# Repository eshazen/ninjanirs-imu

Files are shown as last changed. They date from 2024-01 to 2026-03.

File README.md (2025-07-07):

# ninjanirs-imu

IMU and multiplexer designs for ninjaNIRS.  PCBs in this repo:

* `KiCAD/imu-adapter` - programming adapter for MCU programming (for V1 and V2)
* `KiCAD/imu-board` - the IMU board.  Now V2.  Accommodates an optional RJ-11 jack on the back
* `KiCAD/imu-rj-adapter` - RJ-11 adapter for V1 IMU boards (obsolete)
* `KiCAD/imu-splitter` - splitter for connecting IMU to NinjaNIRS readout via ribbon cable (for V1 and V2)

## IMU Board

Board designed in early 2024 along with various adapters and a splitter.
The IMU board has an ATMeg168 so plenty of resources.

### UART connector pinout

    1 - VCC (5V or 3.3V)
	2 - TxD (output from MCU)
	3 - RxD (input to MCU)
	4 - GND
	
### RJ Adapter board pinout

    GND     1
	RxD        2
	TxD     3
	VCC        4

### Using IMU with other systems

The IMU can be used with systems other than NinjaNIRS (fNIRS).  See [OTHERS.md](OTHERS.md) for details.

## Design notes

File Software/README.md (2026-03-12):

# NN24 IMU board software

## Notes

MCU is an ATmega168 in a 28MLF package.

Pinout:

	22 PC3 - LED
    23 PC4 - SDA  (hardware TWI)
	24 PC5 - SCL  (hardware TWI)
	26 PD0 - RxD  (USART Rx)
	27 PD1 - TxD  (USART Tx)
	
Software should be pretty straightforward, since the built-in peripherals can be used.

## Software in this folder

| Folder | Description |
|---|---|
| `arduino-demo` | C code (not Arduino) to test the IMU on an Arduino uno |
| | Prints lines of text with 7 values |
| | |
| `avr-imu-readout` | (obsolete readout software) |
| | Either wait for command byte or timer |
| | Send data in binary or CSV |
| | |
| `avr-imu-blinky` | Blink the LED for quick hardware test |
| | |
| `avr-imu-led-test`  | Read the IMU and encode somehow on the LED |
| | (for easy testing without a UART) |
| | |
| `avr-imu-gpio-test` | **AVR software to readout IMU** |
| | Version using UART Rx as edge trigger for readout |
| | As used by fNIRS at 250k baud (set in `uart.h`) |
| | As used by senior design team 2025 at 9600 baud |
| | |
| `linux-imu-client`  | Linux client to read and display binary data from IMU  |
| | |
| `python-imu` | Python client `imu_250k_test.py` reads fNIRS version |
| | at 250k baud and displays |
| | |
| `BZ_example_code` | Yes |
| | |

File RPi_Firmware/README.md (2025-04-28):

# Raspberry Pi RP2040 Firmware

This directory has firmware images from Bernhard.

`IMUAdapterTestFirmware.uf2` -- Initial version tested 4/2025.  May have J2 Tx/Rx swap.

`IMUAdapterTestFirmware_20250418.uf2` -- Updated version of 4/22/25.  <br>Changes:

* Well defined sample rate of 20 Hz
* Sampling of a 'Sync IN' digital input, and output of its value at the end of the IMU data line
* Corrected the RX/TX swap on J2 of the splitter

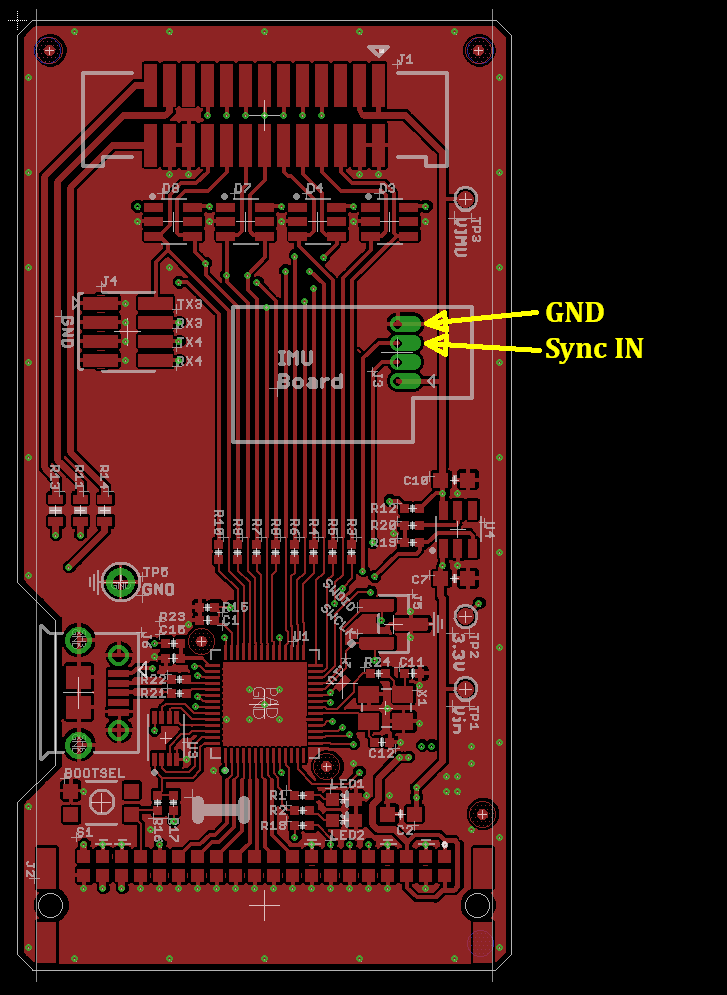
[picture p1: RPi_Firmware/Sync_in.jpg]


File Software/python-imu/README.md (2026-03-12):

# Python test script

`imu_250k_test.py` works for "standard" fNIRS firmware.  This firmware triggers
a readout on any Rx data on the UART and sends a binary frame as below.
The bit rate is 250k.  This works on Linux with an FTDI interface, YMMV.

    Expected binary output:
      <echo> <count> <length> <checksum>
    
    offset 0      <echo>     = xx   echo of byte received
    offset 1      <count>    = 14   normal data, 
    offset 2..15  <data>     =      (7) 16-bit words of Temp, GyroX/Y/Z, Accel X/Y/Z
    offset 16     <checksum> =      uint8_t sum of bytes at offset 1..15
    
    if any error occurs, <count> = 1 and the error code is somehow related
    to the I2C error.

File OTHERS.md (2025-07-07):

# Using the IMU with other systems

This page has some information for using the IMU with non- NinjaNIRS (fNIRS) systems.

The small IMU board comes in two versions.

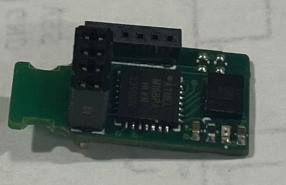
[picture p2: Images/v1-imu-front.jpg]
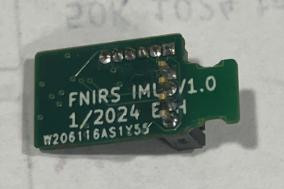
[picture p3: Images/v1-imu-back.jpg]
V1:    

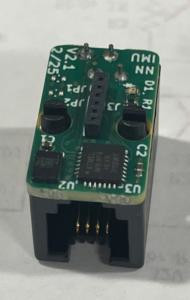
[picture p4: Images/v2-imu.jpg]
V2:  

Both can be used.  The V1 board requires either wires soldered
directly to the board or a separate adapter board which connects to an RJ-11 (modular) jack.

Adapter:  

## Connector Pinouts

| Pin No | Function | Notes |
|---|---|---|
| 1 | VCC | 3.3V power |
| 2 | TxD | Data out from IMU |
| 3 | RxD | Data in or trigger to IMU |
| 4 | GND | Ground |

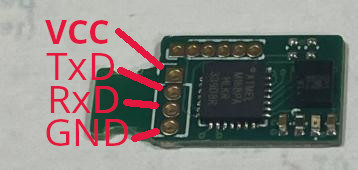
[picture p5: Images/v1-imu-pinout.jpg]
V1 Pinout: 

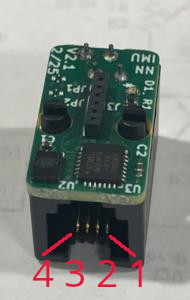
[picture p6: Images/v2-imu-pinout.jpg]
V2 Pinout: 

Pin 2 provides the data out from the IMU.  The firmware supplied for
"other" (non-fNIRS) users can be compiled with various options, but
the usual one is that a pulse on the `RxD` pin causes the IMU data to
be read and transmitted on the `TxD` pin.

Data is transmitted using the asynchronous serial protocol (aka "UART") at 9600 baud.

The default data format is three 16-bit integers separated by commas,
representing acceleration along the X, Y and Z axis.

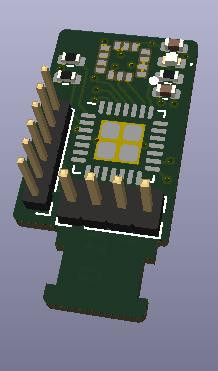
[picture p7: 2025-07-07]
Images/v1-imu-3d.jpg

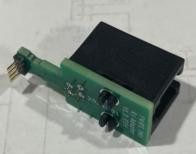
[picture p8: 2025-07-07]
Images/adapter.jpg

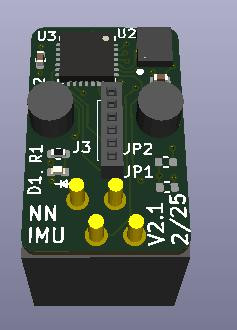
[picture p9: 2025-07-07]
Images/v2-imu-3d.jpg

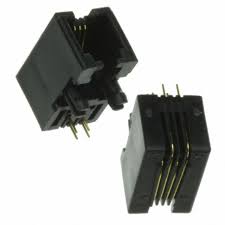
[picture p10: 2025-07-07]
Images/rj11.jpeg

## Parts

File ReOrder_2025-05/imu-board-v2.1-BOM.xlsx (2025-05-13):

 |  |  | NinjaNIRS IMU V2.0 Bill of Materials For Boston University
Item # | *Designator | *Qty | Manufacturer | *Mfg Part # | Description / Value | *Package/Footprint | Type | Your Instructions / Notes
1 | C1, C2 | 1 | KYOCERA | 0402YC104KAT4A | CAP CER 0.1UF 16V X7R 0402 | 0402 (1005 Metric) | SMD
2 | D1 | 1 | SUNLED | XZMDK68W-2 | LED RED CLEAR CHIP SMD | 0402 (1005 Metric) | SMD
3 | R1 | 1 | WALSIN | WR04X6800FTL | RES 680 OHM 1% 1/16W 0402 | 0402 (1005 Metric) | SMD
4 | U2 | 1 | ST | ISM330DHCXTR | INEMO INERTIAL MODULE: ALWAYS-ON | 14-LGA | SMD
5 | U3 | 1 | MICROCHIP | ATMEGA168PA-MMHR | IC MCU 8BIT 16KB FLASH 28VQFN | 28-VQFN | SMD
6 | J3 | 1 | GCT | BC065-06-A-L-D | 6POS 1.0MM PITCH SOCKET, SIL, TH | 6-SIL 1MM | THD
Need a quick and accurante quote? Need an efficient production? Please read SMT Ordering Necessary Files & Info in 1 minute. Thank you very much! (https://www.pcbway.com/smt_ordering_guide.html)
Click for Instructions on How to Create a BOM (https://www.pcbway.com/blog/PCB_Assembly/How_to_Build_a_BOM__Bill_Of_Materials_.html)

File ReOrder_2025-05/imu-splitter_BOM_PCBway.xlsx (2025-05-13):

 |  |  | NinjaNIRS IMU Splitter V2.0 Bill of Materials For Boston University
Item # | *Designator | *Qty | Manufacturer | *Mfg Part # | Description / Value | *Package/Footprint | Type | Your Instructions / Notes
1 | C1 | 1 | Samsung | CL21A106KOQNNNE | 10uF | 0805 | SMD
2 | C2 | 1 | Samsung | CL21A226KOQNNNE | 22uF | 0805 | SMD
3 | D1,D2 | 2 | Dialight | 5973006607F | LED | 0805 | SMD
4 | J1,J2,J3,J4,J5,J6 | 6 | Assman | A-2004-3-4-LP-N-R | CONN MOD JACK 4P4C R/A UNSHLD | MOD JACK | THD
5 | J7 | 1 | CNC Tech | 3220-26-0200-00 | CONN HEADER R/A 26POS 1.27MM | 26 POS 1.27MM | THD
6 | J8 | 1 | Samtec | TMS-104-01-G-S | CONN HEADER VERT 4POS 1.27MM | 4 POS 1.27MM | THD
7 | J9 | 1 | Amphenol | 68000-105HLF | CONN HEADER VERT 5POS 2.54MM | 5 POS 2.54MM | THD
8 | R1 | 1 | Yageo | RC0805FR-071K5L | RES 1.5K OHM 1% 1/8W 0805 | 0805 | SMD
9 | R2 | 1 | Yageo | RC0805FR-07510RL | RES 510 OHM 1% 1/8W 0805 | 0805 | SMD
10 | U1 | 1 | Diodes Inc | AZ1117CH-3.3TRG1 | IC REG LINEAR 3.3V 1A SOT223 | SOT223 | SMD
Need a quick and accurante quote? Need an efficient production? Please read SMT Ordering Necessary Files & Info in 1 minute. Thank you very much! (https://www.pcbway.com/smt_ordering_guide.html)
Click for Instructions on How to Create a BOM (https://www.pcbway.com/blog/PCB_Assembly/How_to_Build_a_BOM__Bill_Of_Materials_.html)

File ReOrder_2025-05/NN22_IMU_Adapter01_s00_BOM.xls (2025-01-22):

PCBWay Bom Quotation, Product No.:T-1Y54W206116A
Item # | *Designator | *Qty | *Mfg Part # | Description / Value | *Package/Footprint | Mounting Type | *Unit Price(4 sets) | *Total | *Delivery Time | *Actual Purchase Mfg Part # | *PCBWay Note | Customer Reply
1 | LED1 | 1 | LTST-C191KRKT | LED RED CLEAR SMD | LED-0603 | SMD | $0.029 | $0.116
2 | LED2 | 1 | LTST-C191KGKT | LED GREEN CLEAR SMD | LED-0603 | SMD | $0.031 | $0.124
3 | C1, C3, C6, C8, C9, C16, C17, C18, C19, C20, C21, C22, C23, C24 | 14 | GRM155R71H104KE14D | CAP CER 0.1UF 50V X7R 0402『 』0.1u『 』0.1u | 0402-CAP | SMD | $0.014 | $0.784
4 | R1, R2, R10, R16, R24 | 5 | RC0402FR-071K2L | RES 1.2K OHM 1% 1/16W 0402『 』1.2k『 』1.2k | 0402-RES | SMD | $0.004 | $0.080
5 | R3, R4, R5, R6, R7, R8, R9 | 7 | RC0402FR-0710RL | 10 Ohms ±1% 0.063W, 1/16W Chip Resistor 0402 (1005 Metric) Moisture Resistant Thick Film『 』10 | 0402-RES | SMD | $0.004 | $0.112
6 | R12, R15, R17, R18, R19, R25, R26 | 7 | RC0402FR-07100KL | RES 100K OHM 1% 1/16W 0402『 』100k『 』100k | 0402-RES | SMD | $0.003 | $0.084
7 | C2, C7, C10 | 3 | GRM188R6YA106MA73D | CAP CER 10UF 35V X5R 0603『 』10u『 』10u | 0603-CAP | SMD | $0.149 | $1.788
8 | R21, R22, R27, R28 | 4 | RC0402FR-0727RL | RES 27 OHM 1% 1/16W 0402『 』27『 』27 | 0402-RES | SMD | $0.005 | $0.080
9 | C11, C12 | 2 | GCM1555C1H270JA16D | CAP CER 27PF 50V C0G/NP0 0402『 』27p『 』27p | 0402-CAP | SMD | $0.088 | $0.704
10 | R23 | 1 | CRCW040233R0FKEDC | RES 33 OHM 1% 1/16W 0402『 』33『 』33 | 0402-RES | SMD | $0.161 | $0.644
11 | C4, C5, C13, C14, C15 | 5 | CL05A475MP5NRNC | CAP CER 4.7UF 10V X5R 0402『 』4.7u『 』4.7u | 0402-CAP | SMD | $0.027 | $0.540
12 | R20 | 1 | RC0402FR-0782KL | RES 82K OHM 1% 1/16W 0402『 』82k | 0402-RES | SMD | $0.012 | $0.048
13 | U4 | 1 | AP22653AW6-7 | LOAD SWITCH,SOT26,T&R,3K『 』AP2265X_SOT | SOT23-6 | SMD | $0.308 | $1.232
14 | D9, D10 | 2 | BAV70WT1G | DIODE ARRAY GP 100V 200MA SC70-3『 』BAV70W | SOT323 | SMD | $0.095 | $0.760
15 | X1 | 1 | 403I35D12M00000 | CRYSTAL 12.0000MHZ 18PF SMD『 』CRYSTAL-3.2-2.5『 』CRYSTAL-3.2-2.5 | CRYSTAL-3.2-2.5 | SMD | $0.798 | $3.192 | 7-10 Workdays
16 | D1, D2, D3, D4, D5, D6, D7, D8 | 8 | D1213A-02SO-7 | TVS DIODE 3.3VWM 10VC SOT26『 』D1213A-02SO | SOT23-6 | SMD | $0.153 | $4.896
17 | R11, R13, R14 | 3 |  | DNP | 0603-RES | DNP |  |  |  |  | [DNP不要贴];
18 | FID1, FID2, FID3, FID4, FID5, FID6, FID7, FID8 | 8 |  | FIDUCIALUFIDUCIAL | MICRO-FIDUCIAL | DNP |  |  |  |  | [DNP不要贴];
20 | J5 | 1 | SM03B-SRSS-TB | CONN HEADER SMD R/A 3POS 1MM |  | SMD
21 | J3, J4 | 2 |  | M04X2_0.050_SMD_NO_CREAM | M04X2_0.050_SMD_NO_CREAM | DNP |  |  |  |  | [DNP不要贴];
22 | J1 | 1 | 3220-26-0300-00 | CONN HEADER SMD 26POS 1.27MM『 』M13X2_0.050_SHF | M13X2_0.050_SHF | SMD | $2.138 | $8.552 | 7-10 Workdays
23 | J2 | 1 | 15150402601000 | CONN HEADER SMD R/A 40POS 1.27MM『 』M20X2_HARFLEX_M | M20X2_HARFLEX_M | SMD | $6.766 | $27.064 | 7-10 Workdays
24 | U2 | 1 | MCP1755-3302E/MC | IC REG LINEAR 3.3V 300MA 8DFN『 』MCP1755_DFN『 』MCP1755_DFN | DFN8_2X3MM | SMD | $1.096 | $4.384 | 7-10 Workdays
25 | U1 | 1 | SC0914(7) | IC MCU 32BIT EXT MEM 56QFN『 』RP2040『 』RP2040 | QFN-56_EP | SMD | $1.441 | $5.764 | 7-10 Workdays
26 | S1 | 1 | KMR231NG LFS | SWITCH TACTILE SPST-NO 0.05A 32V『 』SWITCH-MOMENTARY-2SMD-3『 』SWITCH-MOMENTARY-2SMD-3 | TACTILE_SWITCH_SMD-3 | SMD | $0.910 | $3.640 |  | KMR231NGLFS
27 | TP5 | 1 |  | TESTPOINT1X01 | 1X01 | DNP |  |  |  |  | [DNP不要贴];
28 | TP4 | 1 |  | TESTPOINTPADSMALL | TESTPAD_SMALL | DNP |  |  |  |  | [DNP不要贴];
29 | TP1, TP2, TP3 | 3 |  | TESTPOINT_ROUND | TESTPAD_ROUND | DNP |  |  |  |  | [DNP不要贴];
30 | J6 | 1 | 10118194-0001LF | CONN RCPT USB2.0 MICRO B SMD R/A『 』USB-MICRO『 』USB-MICRO | USB-MICRO | SMD/PTH | $0.318 | $1.272
31 | U3 | 1 | W25Q16JVUXIQ TR | IC FLASH 16MBIT SPI/QUAD 8USON『 』W25Q_USON『 』W25Q_USON | USON8L-2X3MM | SMD | $0.889 | $3.556 | 7-10 Workdays
32 | U5 | 1 | ISM330DHCXTR | Accelerometer, Gyroscope, Temperature, 6 Axis Sensor I2C, SPI Output | LGA14-L | SMD
 |  |  |  |  |  |  | Component Cost | $69.42

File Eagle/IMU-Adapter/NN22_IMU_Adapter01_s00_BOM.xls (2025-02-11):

PCBWay BOM for IMU adapter
Item # | *Designator | *Qty | *Mfg Part # | Description / Value | *Package/Footprint | Mounting Type | *Unit Price(4 sets) | *Total | *Delivery Time | *Actual Purchase Mfg Part # | *PCBWay Note | Customer Reply
1 | LED1 | 1 | LTST-C191KRKT | LED RED CLEAR SMD | LED-0603 | SMD
2 | LED2 | 1 | LTST-C191KGKT | LED GREEN CLEAR SMD | LED-0603 | SMD
3 | C1, C3, C6, C8, C9, C16, C17, C18, C19, C20, C21, C22, C23, C24 | 14 | GRM155R71H104KE14D | CAP CER 0.1UF 50V X7R 0402『 』0.1u『 』0.1u | 0402-CAP | SMD
4 | R1, R2, R10, R16, R24 | 5 | RC0402FR-071K2L | RES 1.2K OHM 1% 1/16W 0402『 』1.2k『 』1.2k | 0402-RES | SMD
5 | R3, R4, R5, R6, R7, R8, R9 | 7 | RC0402FR-0710RL | 10 Ohms ±1% 0.063W, 1/16W Chip Resistor 0402 (1005 Metric) Moisture Resistant Thick Film『 』10 | 0402-RES | SMD
6 | R12, R15, R17, R18, R19, R25, R26 | 7 | RC0402FR-07100KL | RES 100K OHM 1% 1/16W 0402『 』100k『 』100k | 0402-RES | SMD
7 | C2, C7, C10 | 3 | GRM188R6YA106MA73D | CAP CER 10UF 35V X5R 0603『 』10u『 』10u | 0603-CAP | SMD
8 | R21, R22, R27, R28 | 4 | RC0402FR-0727RL | RES 27 OHM 1% 1/16W 0402『 』27『 』27 | 0402-RES | SMD
9 | C11, C12 | 2 | GCM1555C1H270JA16D | CAP CER 27PF 50V C0G/NP0 0402『 』27p『 』27p | 0402-CAP | SMD
10 | R23 | 1 | CRCW040233R0FKEDC | RES 33 OHM 1% 1/16W 0402『 』33『 』33 | 0402-RES | SMD
11 | C4, C5, C13, C14, C15 | 5 | CL05A475MP5NRNC | CAP CER 4.7UF 10V X5R 0402『 』4.7u『 』4.7u | 0402-CAP | SMD
12 | R20 | 1 | RC0402FR-0782KL | RES 82K OHM 1% 1/16W 0402『 』82k | 0402-RES | SMD
13 | U4 | 1 | AP22653AW6-7 | LOAD SWITCH,SOT26,T&R,3K『 』AP2265X_SOT | SOT23-6 | SMD
14 | D9, D10 | 2 | BAV70WT1G | DIODE ARRAY GP 100V 200MA SC70-3『 』BAV70W | SOT323 | SMD
15 | X1 | 1 | 403I35D12M00000 | CRYSTAL 12.0000MHZ 18PF SMD『 』CRYSTAL-3.2-2.5『 』CRYSTAL-3.2-2.5 | CRYSTAL-3.2-2.5 | SMD
16 | D1, D2, D3, D4, D5, D6, D7, D8 | 8 | D1213A-02SO-7 | TVS DIODE 3.3VWM 10VC SOT26『 』D1213A-02SO | SOT23-6 | SMD
17 | R11, R13, R14 | 3 |  | DNP | 0603-RES | DNP
18 | FID1, FID2, FID3, FID4, FID5, FID6, FID7, FID8 | 8 |  | FIDUCIALUFIDUCIAL | MICRO-FIDUCIAL | DNP
20 | J5 | 1 | SM03B-SRSS-TB | CONN HEADER SMD R/A 3POS 1MM |  | SMD
21 | J3, J4 | 2 |  | M04X2_0.050_SMD_NO_CREAM | M04X2_0.050_SMD_NO_CREAM | DNP
22 | J1 | 1 | 3220-26-0300-00 | CONN HEADER SMD 26POS 1.27MM『 』M13X2_0.050_SHF | M13X2_0.050_SHF | SMD
23 | J2 | 1 | 15150402601000 | CONN HEADER SMD R/A 40POS 1.27MM『 』M20X2_HARFLEX_M | M20X2_HARFLEX_M | SMD
24 | U2 | 1 | MCP1755-3302E/MC | IC REG LINEAR 3.3V 300MA 8DFN『 』MCP1755_DFN『 』MCP1755_DFN | DFN8_2X3MM | SMD
25 | U1 | 1 | SC0914(7) | IC MCU 32BIT EXT MEM 56QFN『 』RP2040『 』RP2040 | QFN-56_EP | SMD
26 | S1 | 1 | KMR231NG LFS | SWITCH TACTILE SPST-NO 0.05A 32V『 』SWITCH-MOMENTARY-2SMD-3『 』SWITCH-MOMENTARY-2SMD-3 | TACTILE_SWITCH_SMD-3 | SMD
27 | TP5 | 1 |  | TESTPOINT1X01 | 1X01 | DNP
28 | TP4 | 1 |  | TESTPOINTPADSMALL | TESTPAD_SMALL | DNP
29 | TP1, TP2, TP3 | 3 |  | TESTPOINT_ROUND | TESTPAD_ROUND | DNP
30 | J6 | 1 | 10118194-0001LF | CONN RCPT USB2.0 MICRO B SMD R/A『 』USB-MICRO『 』USB-MICRO | USB-MICRO | SMD/PTH
31 | U3 | 1 | W25Q16JVUXIQ TR | IC FLASH 16MBIT SPI/QUAD 8USON『 』W25Q_USON『 』W25Q_USON | USON8L-2X3MM | SMD
32 | U5 | 1 | ISM330DHCXTR | Accelerometer, Gyroscope, Temperature, 6 Axis Sensor I2C, SPI Output | LGA14-L | SMD

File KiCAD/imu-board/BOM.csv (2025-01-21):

Reference | Value | Footprint | Qty | DNP | CatNo | MfgNo
C1,C2 | 0.1uF | Capacitor_SMD:C_0402_1005Metric | 2 |  | 478-KGM05AR71C104KNCT-ND | 0402YC104KAT4A
D1 | LED | LED_SMD:LED_0402_1005Metric | 1 |  | 1497-1174-1-ND | XZMDK68W-2
J2 | A-2004-3-4-LP-N-R | my_RJ:A-2004-3-4-LP | 1 |  | AE10381-ND | A-2004-3-4-LP-N-R
J3 | -OMIT- | Connector_PinHeader_1.00mm:PinHeader_1x06_P1.00mm_Vertical | 1 |  | 2073-BC075-06-A-L-ACT-ND | BC075-06-A-L-A
JP1,JP2 | -OMIT- | Resistor_SMD:R_0402_1005Metric | 2 | DNP
R1 | 680 | Resistor_SMD:R_0402_1005Metric | 1 |  | 1292-WR04X6800FTLCT-ND | WR04X6800FTL
U2 | ISM330DHCX | models:LGA-14L | 1 |  | 497-19784-1-ND | ISM330DHCXTR
U3 | ATmega168A-MM | my_AVR:QFN-28-1EP_4x4mm_P0.45mm_EP2.4x2.4mm | 1 |  | ATMEGA168PA-MMHRCT-ND | ATMEGA168PA-MMHR

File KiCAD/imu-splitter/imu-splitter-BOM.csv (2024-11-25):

Reference | Value | Datasheet | Footprint | Qty | DNP | CatNo | MfgNo
C1,C2,C3,C4 | C_Small | ~ | Capacitor_SMD:C_0805_2012Metric_Pad1.18x1.45mm_HandSolder | 4
D1,D2,D3,D4,D5,D6,D7,D8 | LED | ~ | LED_SMD:LED_0805_2012Metric_Pad1.15x1.40mm_HandSolder | 8
J1,J2 | Conn_01x08 | ~ | Connector_PinHeader_2.54mm:PinHeader_1x08_P2.54mm_Vertical | 2
J3 | Conn_01x10 | ~ | Connector_PinHeader_2.54mm:PinHeader_1x10_P2.54mm_Vertical | 1
Q3,Q4 | NMOS | https://ngspice.sourceforge.io/docs/ngspice-html-manual/manual.xhtml#cha_MOSFETs | Package_TO_SOT_SMD:SOT-23 | 2 |  | DMN2046U-7DICT-ND | DMN2046U-7
R1,R3,R4,R5,R6,R7,R8,R9 | 470 | ~ | Resistor_SMD:R_0805_2012Metric_Pad1.20x1.40mm_HandSolder | 8
R2 | R_US | ~ | Resistor_SMD:R_0805_2012Metric_Pad1.20x1.40mm_HandSolder | 1
RV1 | R_Potentiometer_US | ~ | Potentiometer_THT:Potentiometer_ACP_CA6-H2,5_Horizontal | 1
U1 | 74LS02 | http://www.ti.com/lit/gpn/sn74ls02 | Package_SO:SOIC-14_3.9x8.7mm_P1.27mm | 1
U3 | 74LS11 | http://www.ti.com/lit/gpn/sn74LS11 | Package_SO:SOIC-14_3.9x8.7mm_P1.27mm | 1
U6 | LMC555xM | http://www.ti.com/lit/ds/symlink/lmc555.pdf | Package_SO:SOIC-8_3.9x4.9mm_P1.27mm | 1 |  | LM555CMX/NOPBCT-ND | LM555CMX/NOPB

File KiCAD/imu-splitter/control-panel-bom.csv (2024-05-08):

Reference | Value | Datasheet | Footprint | Qty | DNP
C1 | 10uF | ~ | Capacitor_SMD:C_0805_2012Metric_Pad1.18x1.45mm_HandSolder | 1
C2 | 22uF | ~ | Capacitor_SMD:C_0805_2012Metric_Pad1.18x1.45mm_HandSolder | 1
D1,D2 | LED | ~ | LED_SMD:LED_0805_2012Metric_Pad1.15x1.40mm_HandSolder | 2
J1,J2,J3,J4,J5,J6 | 4P4C | ~ | my_RJ:A-2004-3-4-LP | 6
J7 | 3220-26-0200-00 | ~ | models:SAMTEC_SHF-113-01-L-D-RA | 1
J8 | Conn_01x04 | ~ | Connector_PinHeader_1.27mm:PinHeader_1x04_P1.27mm_Vertical | 1
J9 | Conn_01x05 | ~ | Connector_PinHeader_2.54mm:PinHeader_1x05_P2.54mm_Vertical | 1
R1 | 1.5k | ~ | Resistor_SMD:R_0805_2012Metric_Pad1.20x1.40mm_HandSolder | 1
R2 | 510 | ~ | Capacitor_SMD:C_0805_2012Metric_Pad1.18x1.45mm_HandSolder | 1
U1 | AP2114H-3.3TRG1 | https://www.diodes.com/assets/Datasheets/AZ1117.pdf | Package_TO_SOT_SMD:SOT-223-3_TabPin2 | 1

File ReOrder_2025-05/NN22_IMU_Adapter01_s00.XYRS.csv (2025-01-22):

#XYRS data for D:/Dropbox/Eagle/Projects/U01/NN2022/IMU/IMU_Adapter/NN22_IMU_Adapter01_s00.brd.
#Board Size is 2500.000000 x 1300.000000.
#
#Placement Data:
#Designator | X-Loc | Y-Loc | Rotation | Side | Type | X-Size | Y-Size | Value | Footprint | Populate | MPN
C1 | 1580.00 | 500.00 | 270 | 1 | 1 | 62.99 | 19.69 | 0.1u | 0402-CAP | 1
C2 | 2090.00 | 1010.00 | 270 | 1 | 1 | 110.24 | 35.43 | 10u | 0603-CAP | 1
C3 | 2120.00 | 1145.00 | 270 | 2 | 1 | 62.99 | 19.69 | 0.1u | 0402-CAP | 1
C4 | 1900.00 | 1145.00 | 270 | 2 | 1 | 62.99 | 19.69 | 4.7u | 0402-CAP | 1
C5 | 1905.00 | 645.00 | 0 | 2 | 1 | 62.99 | 19.69 | 4.7u | 0402-CAP | 1
C6 | 1905.00 | 390.00 | 270 | 2 | 1 | 62.99 | 19.69 | 0.1u | 0402-CAP | 1
C7 | 970.00 | 1150.00 | 90 | 1 | 1 | 110.24 | 35.43 | 10u | 0603-CAP | 1
C8 | 905.00 | 1140.00 | 270 | 2 | 1 | 62.99 | 19.69 | 0.1u | 0402-CAP | 1
C9 | 775.00 | 1140.00 | 270 | 2 | 1 | 62.99 | 19.69 | 0.1u | 0402-CAP | 1
C10 | 710.00 | 1150.00 | 90 | 1 | 1 | 110.24 | 35.43 | 10u | 0603-CAP | 1
C11 | 1720.00 | 1040.00 | 90 | 1 | 1 | 62.99 | 19.69 | 27p | 0402-CAP | 1
C12 | 1900.00 | 960.00 | 90 | 1 | 1 | 62.99 | 19.69 | 27p | 0402-CAP | 1
C13 | 1730.00 | 540.00 | 270 | 2 | 1 | 62.99 | 19.69 | 4.7u | 0402-CAP | 1
C14 | 1685.00 | 410.00 | 90 | 2 | 1 | 62.99 | 19.69 | 4.7u | 0402-CAP | 1
C15 | 1680.00 | 410.00 | 270 | 1 | 1 | 62.99 | 19.69 | 4.7u | 0402-CAP | 1
C16 | 1765.00 | 755.00 | 90 | 2 | 1 | 62.99 | 19.69 | 0.1u | 0402-CAP | 1
C17 | 1810.00 | 540.00 | 270 | 2 | 1 | 62.99 | 19.69 | 0.1u | 0402-CAP | 1
C18 | 1770.00 | 540.00 | 270 | 2 | 1 | 62.99 | 19.69 | 0.1u | 0402-CAP | 1
C19 | 1905.00 | 690.00 | 0 | 2 | 1 | 62.99 | 19.69 | 0.1u | 0402-CAP | 1
C20 | 1805.00 | 755.00 | 90 | 2 | 1 | 62.99 | 19.69 | 0.1u | 0402-CAP | 1
C21 | 1685.00 | 690.00 | 180 | 2 | 1 | 62.99 | 19.69 | 0.1u | 0402-CAP | 1
C22 | 1945.00 | 530.00 | 90 | 2 | 1 | 62.99 | 19.69 | 0.1u | 0402-CAP | 1
C23 | 1625.00 | 490.00 | 90 | 2 | 1 | 62.99 | 19.69 | 0.1u | 0402-CAP | 1
C24 | 1095.00 | 1020.00 | 90 | 1 | 1 | 62.99 | 19.69 | 0.1u | 0402-CAP | 1
D1 | 530.00 | 980.00 | 90 | 2 | 1 | 149.61 | 96.46 | D1213A-02SO | SOT23-6 | 1
D2 | 530.00 | 790.00 | 90 | 2 | 1 | 149.61 | 96.46 | D1213A-02SO | SOT23-6 | 1
D3 | 530.00 | 980.00 | 90 | 1 | 1 | 149.61 | 96.46 | D1213A-02SO | SOT23-6 | 1
D4 | 530.00 | 790.00 | 90 | 1 | 1 | 149.61 | 96.46 | D1213A-02SO | SOT23-6 | 1
D5 | 530.00 | 600.00 | 90 | 2 | 1 | 149.61 | 96.46 | D1213A-02SO | SOT23-6 | 1
D6 | 530.00 | 410.00 | 90 | 2 | 1 | 149.61 | 96.46 | D1213A-02SO | SOT23-6 | 1
D7 | 530.00 | 600.00 | 90 | 1 | 1 | 149.61 | 96.46 | D1213A-02SO | SOT23-6 | 1
D8 | 530.00 | 410.00 | 90 | 1 | 1 | 149.61 | 96.46 | D1213A-02SO | SOT23-6 | 1
D9 | 2100.00 | 1010.00 | 270 | 2 | 1 | 110.24 | 78.74 | BAV70W | SOT323 | 1
D10 | 1980.00 | 1010.00 | 270 | 2 | 1 | 110.24 | 78.74 | BAV70W | SOT323 | 1
FID1 | 80.00 | 1215.00 | 0 | 1 | 1 | 25.00 | 25.00 | FIDUCIALUFIDUCIAL | MICRO-FIDUCIAL | 1
FID2 | 80.00 | 85.00 | 0 | 1 | 1 | 25.00 | 25.00 | FIDUCIALUFIDUCIAL | MICRO-FIDUCIAL | 1
FID3 | 2090.00 | 1225.00 | 0 | 1 | 1 | 25.00 | 25.00 | FIDUCIALUFIDUCIAL | MICRO-FIDUCIAL | 1
FID4 | 80.00 | 1220.00 | 0 | 2 | 1 | 25.00 | 25.00 | FIDUCIALUFIDUCIAL | MICRO-FIDUCIAL | 1
FID5 | 80.00 | 80.00 | 0 | 2 | 1 | 25.00 | 25.00 | FIDUCIALUFIDUCIAL | MICRO-FIDUCIAL | 1
FID6 | 2430.00 | 1220.00 | 0 | 2 | 1 | 25.00 | 25.00 | FIDUCIALUFIDUCIAL | MICRO-FIDUCIAL | 1
FID7 | 1965.00 | 815.00 | 0 | 1 | 1 | 25.00 | 25.00 | FIDUCIALUFIDUCIAL | MICRO-FIDUCIAL | 1
FID8 | 1635.00 | 485.00 | 0 | 1 | 1 | 25.00 | 25.00 | FIDUCIALUFIDUCIAL | MICRO-FIDUCIAL | 1
J1 | 250.00 | 650.00 | 0 | 1 | 1 | 270.00 | 630.00 | M13X2_0.050_SHF | M13X2_0.050_SHF | 1
J2 | 2313.86 | 650.00 | 90 | 1 | 1 | 1194.88 | 299.21 | M20X2_HARFLEX_M | M20X2_HARFLEX_M | 1
J3 | 1380.00 | 1055.00 | 90 | 2 | 1 | 232.00 | 180.00 | M04X2_0.050_SMD_NO_CREAM | M04X2_0.050_SMD_NO_CREAM | 1
J4 | 820.00 | 290.00 | 90 | 1 | 1 | 232.00 | 180.00 | M04X2_0.050_SMD_NO_CREAM | M04X2_0.050_SMD_NO_CREAM | 1
J5 | 1540.00 | 1070.75 | 180 | 1 | 1 | 228.35 | 218.50 | M03X1_JST_SH_RA | M03X1_JST_SH_SM_RA | 1
J6 | 1770.00 | 211.67 | 0 | 1 | 2 | 322.83 | 164.37 | USB-MICRO | USB-MICRO | 1
LED1 | 2050.00 | 860.00 | 0 | 1 | 1 | 31.50 | 90.55 |  | LED-0603 | 1
LED2 | 2105.00 | 860.00 | 0 | 1 | 1 | 31.50 | 90.55 |  | LED-0603 | 1
R1 | 2040.00 | 750.00 | 270 | 1 | 1 | 62.99 | 23.62 | 1.2k | 0402-RES | 1
R2 | 2080.00 | 750.00 | 270 | 1 | 1 | 62.99 | 23.62 | 1.2k | 0402-RES | 1
R3 | 1400.00 | 880.00 | 0 | 1 | 1 | 62.99 | 23.62 | 10 | 0402-RES | 1
R4 | 1400.00 | 780.00 | 180 | 1 | 1 | 62.99 | 23.62 | 10 | 0402-RES | 1
R5 | 1400.00 | 830.00 | 0 | 1 | 1 | 62.99 | 23.62 | 10 | 0402-RES | 1
R6 | 1400.00 | 730.00 | 180 | 1 | 1 | 62.99 | 23.62 | 10 | 0402-RES | 1
R7 | 1400.00 | 630.00 | 0 | 1 | 1 | 62.99 | 23.62 | 10 | 0402-RES | 1
R8 | 1400.00 | 680.00 | 180 | 1 | 1 | 62.99 | 23.62 | 10 | 0402-RES | 1
R9 | 1400.00 | 580.00 | 0 | 1 | 1 | 62.99 | 23.62 | 10 | 0402-RES | 1
R10 | 1400.00 | 530.00 | 180 | 1 | 1 | 62.99 | 23.62 | 1.2k | 0402-RES | 1
R11 | 1290.00 | 165.00 | 180 | 1 | 1 | 82.68 | 35.43 | DNP | 0603-RES | 1
R12 | 785.00 | 1040.00 | 90 | 1 | 1 | 62.99 | 23.62 | 100k | 0402-RES | 1
R13 | 1290.00 | 100.00 | 180 | 1 | 1 | 82.68 | 35.43 | DNP | 0603-RES | 1
R14 | 1290.00 | 230.00 | 180 | 1 | 1 | 82.68 | 35.43 | DNP | 0603-RES | 1
R15 | 1545.00 | 500.00 | 90 | 1 | 1 | 62.99 | 23.62 | 100k | 0402-RES | 1
R16 | 2060.00 | 370.00 | 180 | 1 | 1 | 62.99 | 23.62 | 1.2k | 0402-RES | 1
R17 | 2060.00 | 410.00 | 0 | 1 | 1 | 62.99 | 23.62 | 100k | 0402-RES | 1
R18 | 2120.00 | 750.00 | 270 | 1 | 1 | 62.99 | 23.62 | 100k | 0402-RES | 1
R19 | 875.00 | 1040.00 | 90 | 1 | 1 | 62.99 | 23.62 | 100k | 0402-RES | 1
R20 | 830.00 | 1040.00 | 90 | 1 | 1 | 62.99 | 23.62 | 82k | 0402-RES | 1
R21 | 1772.00 | 426.00 | 270 | 1 | 1 | 62.99 | 23.62 | 27 | 0402-RES | 1
R22 | 1735.00 | 426.00 | 270 | 1 | 1 | 62.99 | 23.62 | 27 | 0402-RES | 1
R23 | 1640.00 | 410.00 | 90 | 1 | 1 | 62.99 | 23.62 | 33 | 0402-RES | 1
R24 | 1720.00 | 950.00 | 90 | 1 | 1 | 62.99 | 23.62 | 1.2k | 0402-RES | 1
R25 | 1350.00 | 1110.00 | 90 | 1 | 1 | 62.99 | 23.62 | 100k | 0402-RES | 1
R26 | 1300.00 | 1110.00 | 90 | 1 | 1 | 62.99 | 23.62 | 100k | 0402-RES | 1
R27 | 1620.00 | 900.00 | 180 | 1 | 1 | 62.99 | 23.62 | 27 | 0402-RES | 1
R28 | 1620.00 | 860.00 | 180 | 1 | 1 | 62.99 | 23.62 | 27 | 0402-RES | 1
S1 | 2060.00 | 220.00 | 90 | 1 | 1 | 196.85 | 102.36 | SWITCH-MOMENTARY-2SMD-3 | TACTILE_SWITCH_SMD-3 | 1
TP1 | 1760.00 | 1180.00 | 0 | 1 | 1 | 40.00 | 40.00 | TESTPOINT_ROUND | TESTPAD_ROUND | 1
TP2 | 1250.00 | 400.00 | 0 | 1 | 1 | 40.00 | 40.00 | TESTPOINT_ROUND | TESTPAD_ROUND | 1
TP3 | 470.00 | 1180.00 | 0 | 1 | 1 | 40.00 | 40.00 | TESTPOINT_ROUND | TESTPAD_ROUND | 1
TP4 | 1745.00 | 855.00 | 135 | 1 | 1 | 40.00 | 20.00 | TESTPOINTPADSMALL | TESTPAD_SMALL | 1
TP5 | 1480.00 | 270.00 | 0 | 1 | 2 | 43.31 | 43.31 | TESTPOINT1X01 | 1X01 | 1
U1 | 1800.00 | 650.00 | 180 | 1 | 1 | 305.12 | 305.12 | RP2040 | QFN-56_EP | 1
U2 | 2010.00 | 1145.00 | 180 | 2 | 1 | 143.70 | 70.87 | MCP1755_DFN | DFN8_2X3MM | 1
U3 | 1890.00 | 390.00 | 180 | 1 | 1 | 143.70 | 70.87 | W25Q_USON | USON8L-2X3MM | 1
U4 | 840.00 | 1160.00 | 180 | 1 | 1 | 149.61 | 96.46 | AP2265X_SOT | SOT23-6 | 1
U5 | 1190.00 | 1060.00 | 270 | 1 | 1 | 115.35 | 95.67 | ISM330DHCX | LGA14-L | 1
X1 | 1810.00 | 970.00 | 270 | 1 | 1 | 141.73 | 114.17 | CRYSTAL-3.2-2.5 | CRYSTAL-3.2-2.5 | 1

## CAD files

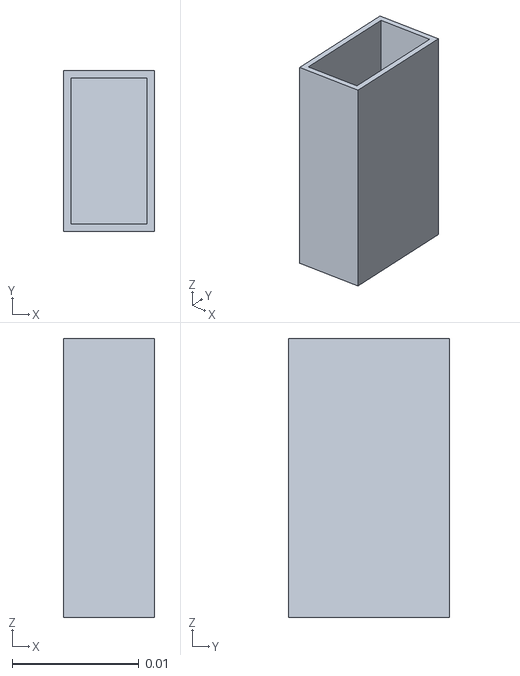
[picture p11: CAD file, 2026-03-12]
Case/imu-box-small.stl
0.0072 x 0.0127 x 0.022

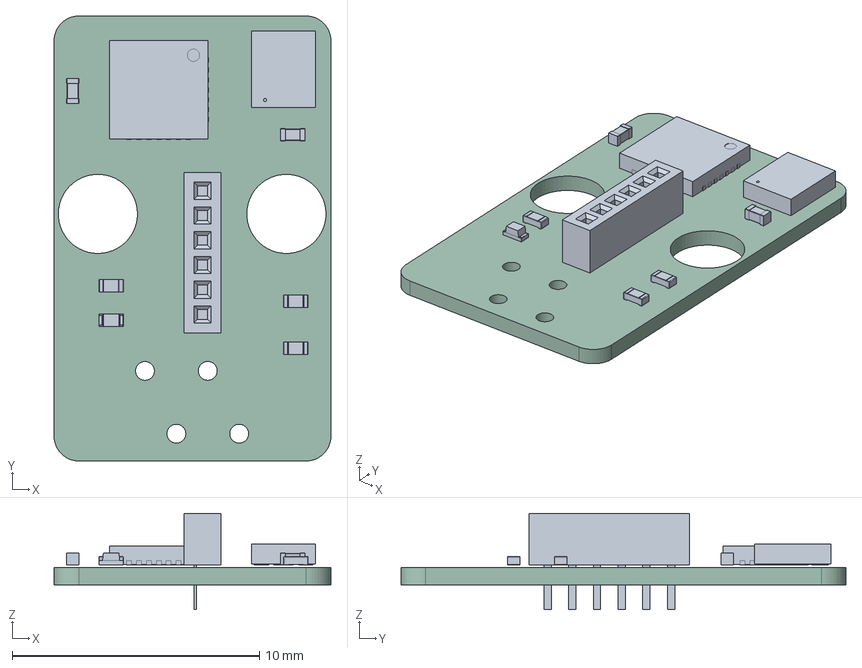
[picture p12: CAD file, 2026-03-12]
KiCAD/imu-board/imu-board.step
11.2 x 18.0 x 3.90 mm
C_0402_1005Metric x 2
QFN-28-1EP_4x4mm_P0.4mm_EP2.4x2.4mm
LED_0402_1005Metric
LGA-14L_STM
R_0402_1005Metric x 3
BC065-xxx body_06
pin^BC065- xxxx Ass x 6
imu-board_PCB

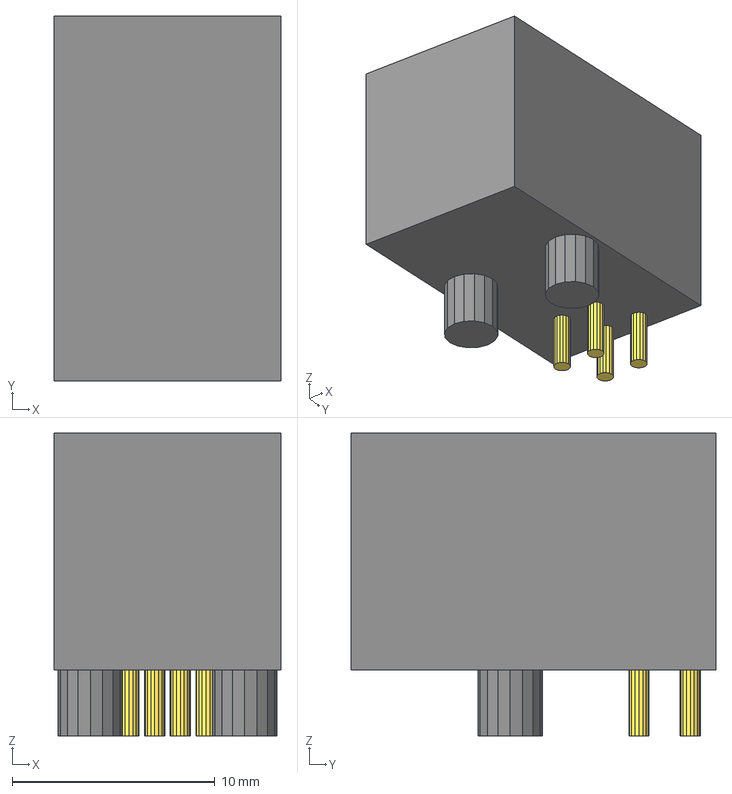
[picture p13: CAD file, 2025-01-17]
KiCAD/imu-board/models/RJ11.step
11.2 x 18.0 x 14.9 mm

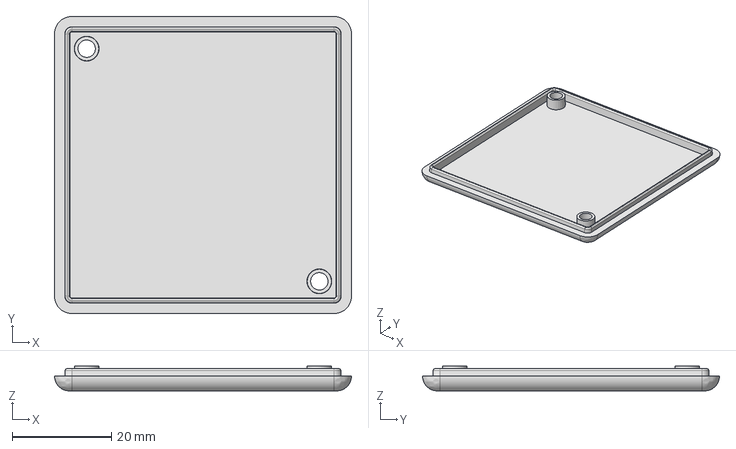
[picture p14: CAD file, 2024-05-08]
KiCAD/imu-splitter/3D/1551T_Lid_transparent.FCStd
60.0 x 60.0 x 5.00 mm

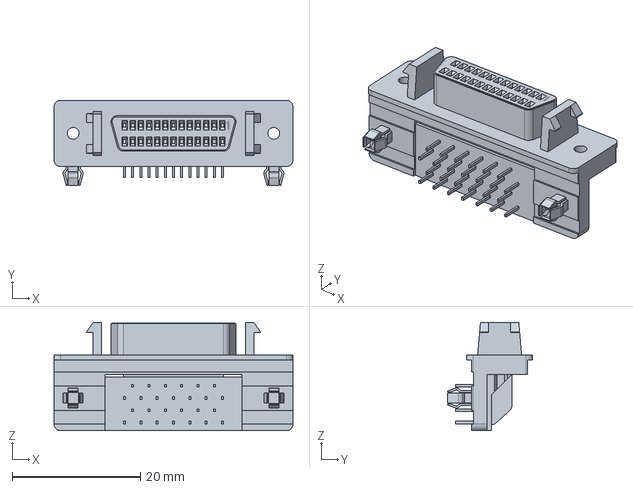
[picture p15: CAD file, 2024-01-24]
KiCAD/imu-splitter/models/c-5787082-2-a-3d.stp
37.2 x 13.3 x 16.9 mm

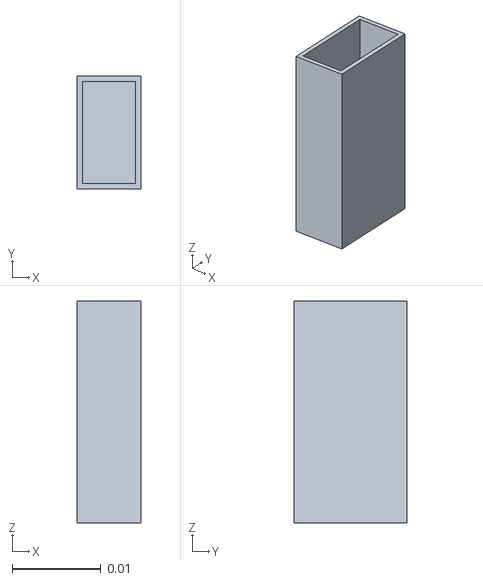
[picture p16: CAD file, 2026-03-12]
Case/imu-box-small-25mm.stl
0.0072 x 0.0127 x 0.025

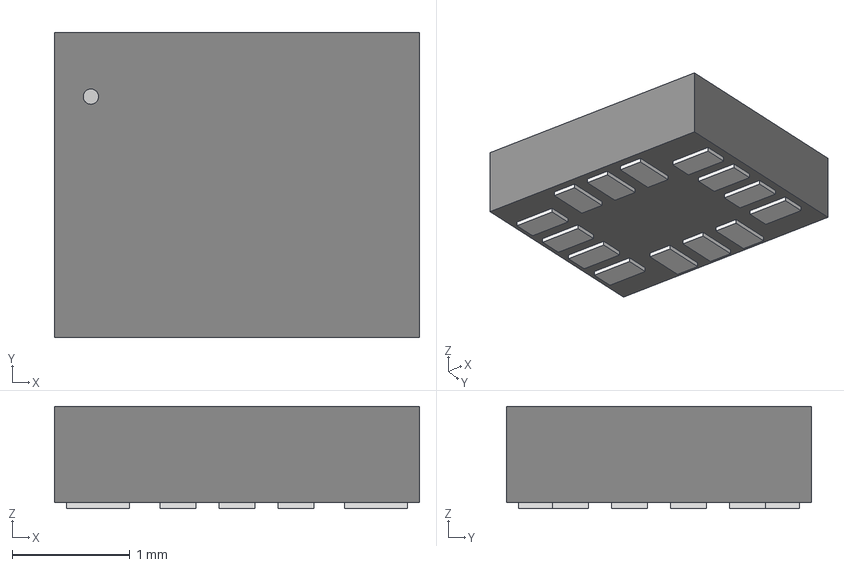
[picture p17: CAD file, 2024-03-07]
KiCAD/imu-board/models/LGA-14L_STM.step
3.10 x 2.59 x 0.866 mm

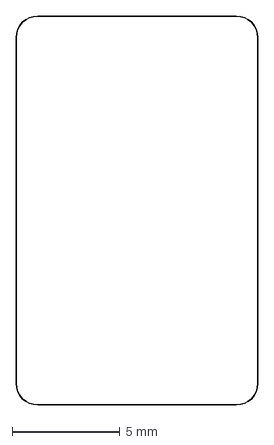
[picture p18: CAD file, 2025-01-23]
KiCAD/imu-board/rounded_board.dxf
11.2 x 18.0 mm

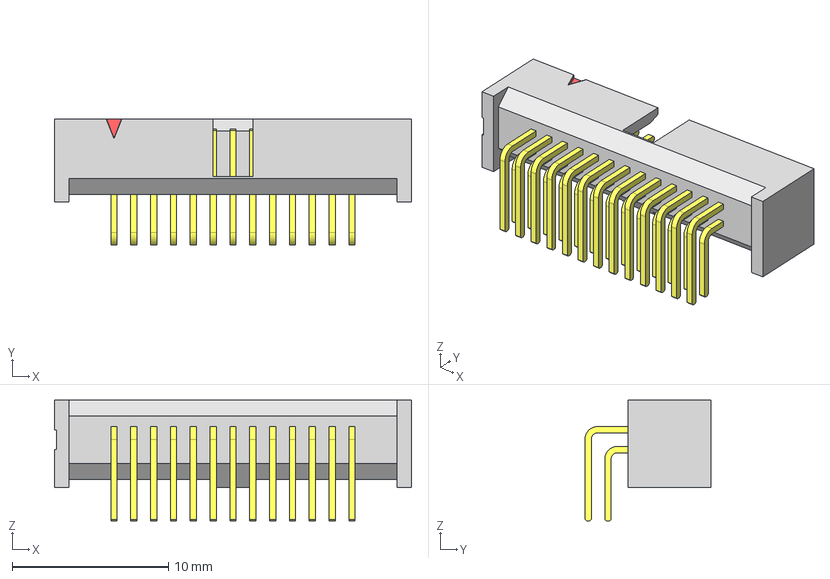
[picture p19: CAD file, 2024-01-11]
KiCAD/imu-splitter/models/SHF-113-01-L-D-RA.step
22.9 x 8.08 x 7.75 mm
T-1S71-02-13-D-RA
SHF-First_Position_Indicator
SHF-113-01-D_header

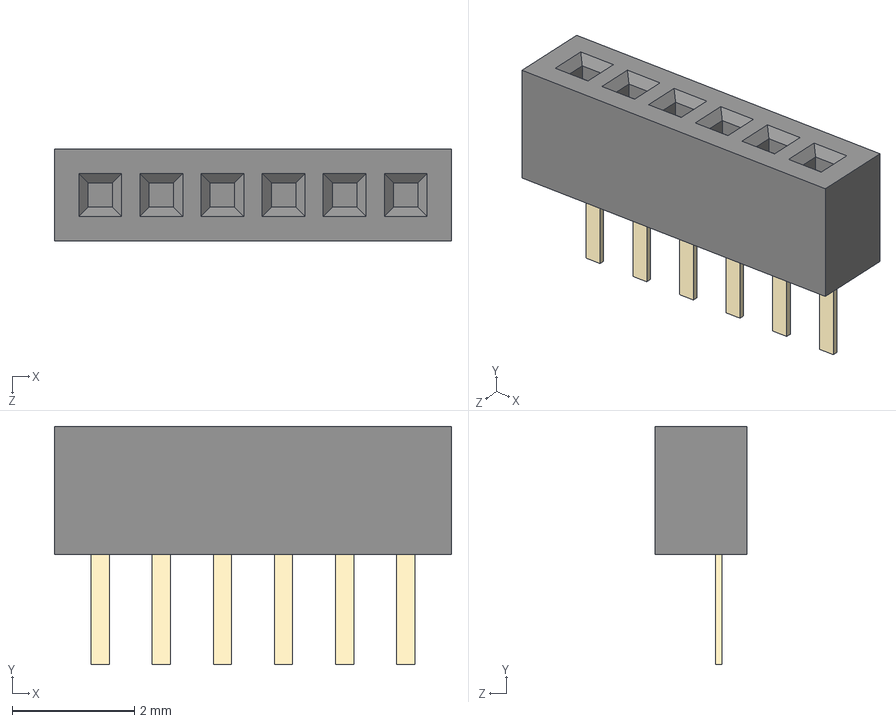
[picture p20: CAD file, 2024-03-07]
KiCAD/imu-board/models/BC065-06-A-L-D.STEP
6.50 x 3.90 x 1.50 mm
BC065-xxx body_06
pin^BC065- xxxx Ass x 6

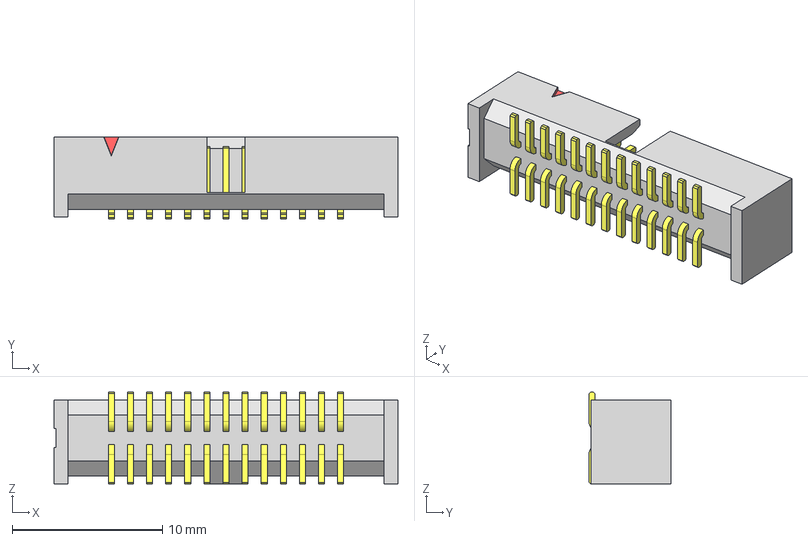
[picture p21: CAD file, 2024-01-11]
KiCAD/imu-splitter/models/SHF-113-01-L-D-SM.step
22.9 x 5.46 x 6.10 mm
T-1S71-02-13-D-SM
SHF-First_Position_Indicator
SHF-113-01-D_header

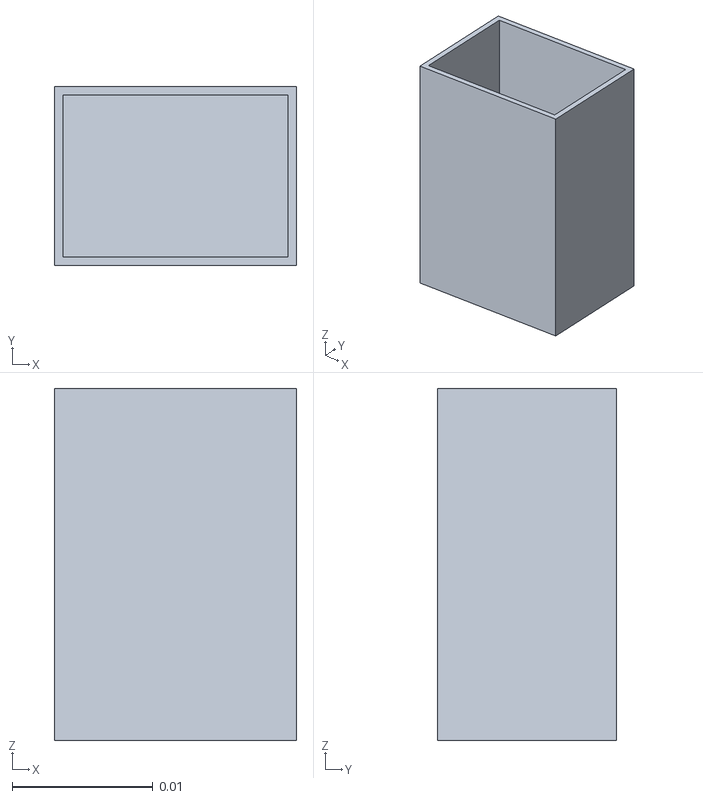
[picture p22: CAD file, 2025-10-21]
Case/imu-box.stl
0.0172 x 0.0127 x 0.025

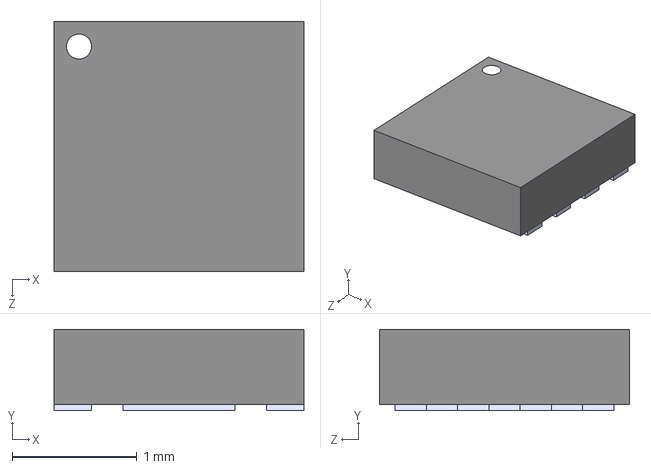
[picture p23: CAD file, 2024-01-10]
KiCAD/imu-board/models/ATTINY10-MAHR.step
2.00 x 0.65 x 2.00 mm

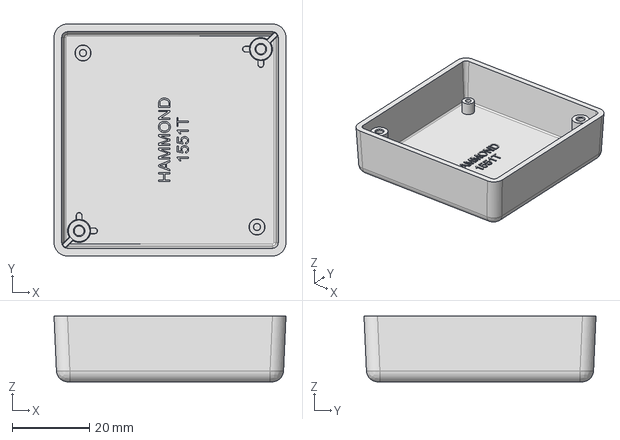
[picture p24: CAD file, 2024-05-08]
KiCAD/imu-splitter/3D/1551T_Box.step
60.0 x 60.0 x 17.0 mm

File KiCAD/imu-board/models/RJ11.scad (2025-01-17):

// Assman RJ-11 thru-hole
//
// from https://www.assmann-wsw.com/uploads/datasheets/ASS_7041_CO.pdf

$fn=16;

module rj11() {
     color("#404040") {
	  cube( [11.2, 18, 11.7]);
	  translate( [(11.2-7.62)/2, 7.85, -3.25]) {
	       cylinder( h=3.25, d=3.2);
	       translate( [7.62, 0, 0])
		    cylinder( h=3.25, d=3.2);
	  }
     }
     color("gold") {
	  translate( [(11.2-3*1.27)/2, 7.85+8.89-2.54, -3.25]) {
	       cylinder( h=3.25, d=1);
	       translate( [2.54, 0, 0]) cylinder( h=3.25, d=1);
	       translate( [1.27, 2.54, 0]) cylinder( h=3.25, d=1);
	       translate( [1.27+2.54, 2.54, 0]) cylinder( h=3.25, d=1);
	  }
     }
}

rj11();

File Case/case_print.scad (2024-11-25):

//
// Reproduce (more or less) Hammond 1551T enclosure
// for 3D printing
//

$fn = 32;
e = 0.1;

case_out = 60;			/* outer size */
case_in = 56;			/* inner size */
case_ext = 6;			/* height extend beyond stock */
case_hgt = 17+case_ext;		/* box height */

bot_hgt = 2;			/* bottom height (thickness) */

so_dia = 4;			/* board standoff diam */
so_hol = 1.725;			/* board standoff hole diam */
so_hgt = 4;			/* board standoff height above base */
so_xy = 7.5;			/* standoff offset from corner */

out_rad = 3.5;			/* outer corner radius */
in_rad = out_rad-(case_out-case_in)/2; /* inner corner radius */

pcb_thk = 1.6;
pcb_top = so_hgt+bot_hgt+pcb_thk; /* PCB top surface Z */

// RJ cutout dims
rj_wid = 11.5;			/* mfg dim 11.2 */
// rj_hgt = 12.0;			/* mfg dim 11.7 */
rj_hgt = 20.0;			/* mfg dim 11.7 */

// lid support standoff
lid_hgt = 13+case_ext;
lid_dia = 5.6;
lid_hol = 2.5;

// lid support standoff
module lid_at( x, y) {
  translate( [x, y, bot_hgt-e]) {
    difference() {
      cylinder( h=lid_hgt, d=lid_dia);
      cylinder( h=lid_hgt+e, d=lid_hol);
    }
  }
}

// board mount standoff
module standoff_at( x, y) {
  translate( [x, y, bot_hgt-e]) {
    difference() {
      cylinder( h=so_hgt, d=so_dia);
      cylinder( h=so_hgt+e, d=so_hol);
    }
  }
}

module outer_wall() {
    hull() {
      translate( [out_rad, out_rad, 0]) circle( out_rad);
      translate( [case_out-out_rad, case_out-out_rad, 0]) circle( out_rad);
      translate( [out_rad, case_out-out_rad, 0]) circle( out_rad);
      translate( [case_out-out_rad, out_rad, 0]) circle( out_rad);
    }
}

module inner_wall() {
      hull() {
      translate( [in_rad, in_rad, 0]) circle( in_rad);
      translate( [case_in-in_rad, case_in-in_rad, 0]) circle( in_rad);
      translate( [in_rad, case_in-in_rad, 0]) circle( in_rad);
      translate( [case_in-in_rad, in_rad, 0]) circle( in_rad);
    }
}

module case_walls() {
  linear_extrude( height=case_hgt)
    difference() {
    outer_wall();
    translate( [(case_out-case_in)/2, (case_out-case_in)/2, 0])
      inner_wall();
  }
}

// RJ-11 cutout at center (x, y)
module rj11_at( x, y) {
  translate( [x, y, pcb_top])
    translate( [-rj_wid/2, -5, 0])
    cube( [rj_wid, 10, rj_hgt]);
}

// 26 pin ribbon cutout dims
rib_wid = 24.0;			/* mfg dim 22.9 */
rib_hgt = 6.0;			/* mfg dim 5.0 */

// ribbon cutout at center (x, y);
module rib_at( x, y) {
  translate( [x, y, pcb_top])
    translate( [-rib_wid/2, -5, 0])
    cube( [rib_wid, 10, rib_hgt]);
}

// model the box
module box() {
  case_walls();			/* walls with radius */
  linear_extrude( height=bot_hgt) outer_wall(); /* bottom */
  standoff_at( case_out-so_xy, so_xy);
  standoff_at( so_xy, case_out-so_xy);
  lid_at( case_out-so_xy-46, so_xy-1);
  lid_at( so_xy+46, case_out-so_xy+1);
}

difference() {
  box();
  // top RJ-11
  rj11_at( so_xy+12.5, case_out);
  rj11_at( so_xy+30.7, case_out);
  // bottom RJ-11
  rj11_at( so_xy+12.8, 0);
  rj11_at( so_xy+30.5, 0);
  // right RJ-11
  rotate( [0, 0, 90]) {
    rj11_at( so_xy+15.9, -case_out);
    rj11_at( so_xy+29.5, -case_out);
  }
  rotate( [0, 0, 90]) {
    rib_at( case_out-so_xy-23.5, 0);
  }
}

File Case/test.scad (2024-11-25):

linear_extrude( height=5)
import("hammond_wall_outer.dxf");

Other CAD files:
Adapter/outline.dxf
KiCAD/imu-splitter/3D/1551T_Lid_trans.step
KiCAD/imu-splitter/3D/1551T_Lid.step
KiCAD/imu-splitter/3D/A-2004-3-4.scad
Case/#1551TBK.dwg
Case/1551TBK.dwg
Case/case_print.stl
Case/case_print2.stl
Case/circle.dxf
Case/hammond_wall_inner.dxf
Case/hammond_wall_outer.dxf
Case/hammond_wall_xs.dxf
Case/imu-board.stl
KiCAD/imu-board/models/ISM330DHCX.step
KiCAD/imu-splitter/3D/1551T.dxf
KiCAD/imu-splitter/3D/1551TGY.stp
KiCAD/imu-splitter/3D/A-2004-3-4-Group.step

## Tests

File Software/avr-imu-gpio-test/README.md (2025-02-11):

# avr-imu-gpio-test

Readout the IMU in response to a trigger on the "UART Rx" pin (PD0)

Text data option:

Send a CSV record of up to 7 decimal values with comma separator.
<br>Can choose first variable to send with FIRST_VAR
<br>   temp = 0, gyro = 1..3, Accel = 4..6

Binary data option.  All 16-bit values sent LSB first.

| Offset | Value | Size | Notes |
|---|---|---|---|
| 0 | echo | 8 bits  | received byte |
| 1 | count | 8 bits  | = 14 |
| 2, 3 | temp | 16 bits | raw temperature |
| 4, 5 | gyro_x | 16 bits | raw gyro reading |
| 6, 7 | gyro_y | 16 bits | |
| 8, 9 | gyro_z | 16 bits | |
| 10, 11 | accel_x  | 16 bits | |
| 12, 13 | accel_y  | 16 bits | |
| 14, 15 | accel_z  | 16 bits | |
| 16 | checksum | 8 bits  | unsigned sum of offsets 1..15 |

Error response (may not be a complete list):

| Offset | Value | Size | Notes | |
|---|---|---|---|---|
| 0 | echo | 8 bits | received byte | |
| 1 | count | 8 bits | = 1 | |
| 2 | error | 8 bits | | |
| | | | 0x20 | NAK received after sending device address for writing |
| | | | 0x30 | NAK received after sending data |
| | | | 0x38 | Arbitration lost with address or data |
| | | | 0x48 | NAK received after sending device address for reading |
| | | | 0xff | unexpected data from IMU |
| 3 | checksum | 8 bits | | unsigned sum of offsets 1, 2 |

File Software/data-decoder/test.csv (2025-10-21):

x-axis | 1 | REF1
second | Volt | Volt
+486.200000E-06 |  | +3.187939628959E+00
+486.201600E-06 |  | +3.187939628959E+00
+486.203200E-06 |  | +3.187939628959E+00
+486.204800E-06 |  | +3.187939628959E+00
+486.206400E-06 |  | +3.187939628959E+00
+486.208000E-06 |  | +3.187939628959E+00
+486.209600E-06 |  | +3.187939628959E+00
+486.211200E-06 |  | +3.187939628959E+00
+486.212800E-06 |  | +3.187939628959E+00
+486.214400E-06 |  | +3.187939628959E+00
+486.216000E-06 |  | +3.187939628959E+00
+486.217600E-06 |  | +3.187939628959E+00
+486.219200E-06 |  | +3.187939628959E+00
+486.220800E-06 |  | +3.187939628959E+00
+486.222400E-06 |  | +3.187939628959E+00
+486.224000E-06 |  | +3.187939628959E+00
+486.225600E-06 |  | +3.187939628959E+00
+486.227200E-06 |  | +3.187939628959E+00
+486.228800E-06 |  | +3.187939628959E+00
+486.230400E-06 |  | +3.187939628959E+00
+486.232000E-06 |  | +3.187939628959E+00
+486.233600E-06 |  | +3.187939628959E+00
+486.235200E-06 |  | +3.187939628959E+00
+486.236800E-06 |  | +3.187939628959E+00
+486.238400E-06 |  | +3.187939628959E+00
+486.240000E-06 |  | +3.187939628959E+00
+486.241600E-06 |  | +3.187939628959E+00
+486.243200E-06 |  | +3.187939628959E+00
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

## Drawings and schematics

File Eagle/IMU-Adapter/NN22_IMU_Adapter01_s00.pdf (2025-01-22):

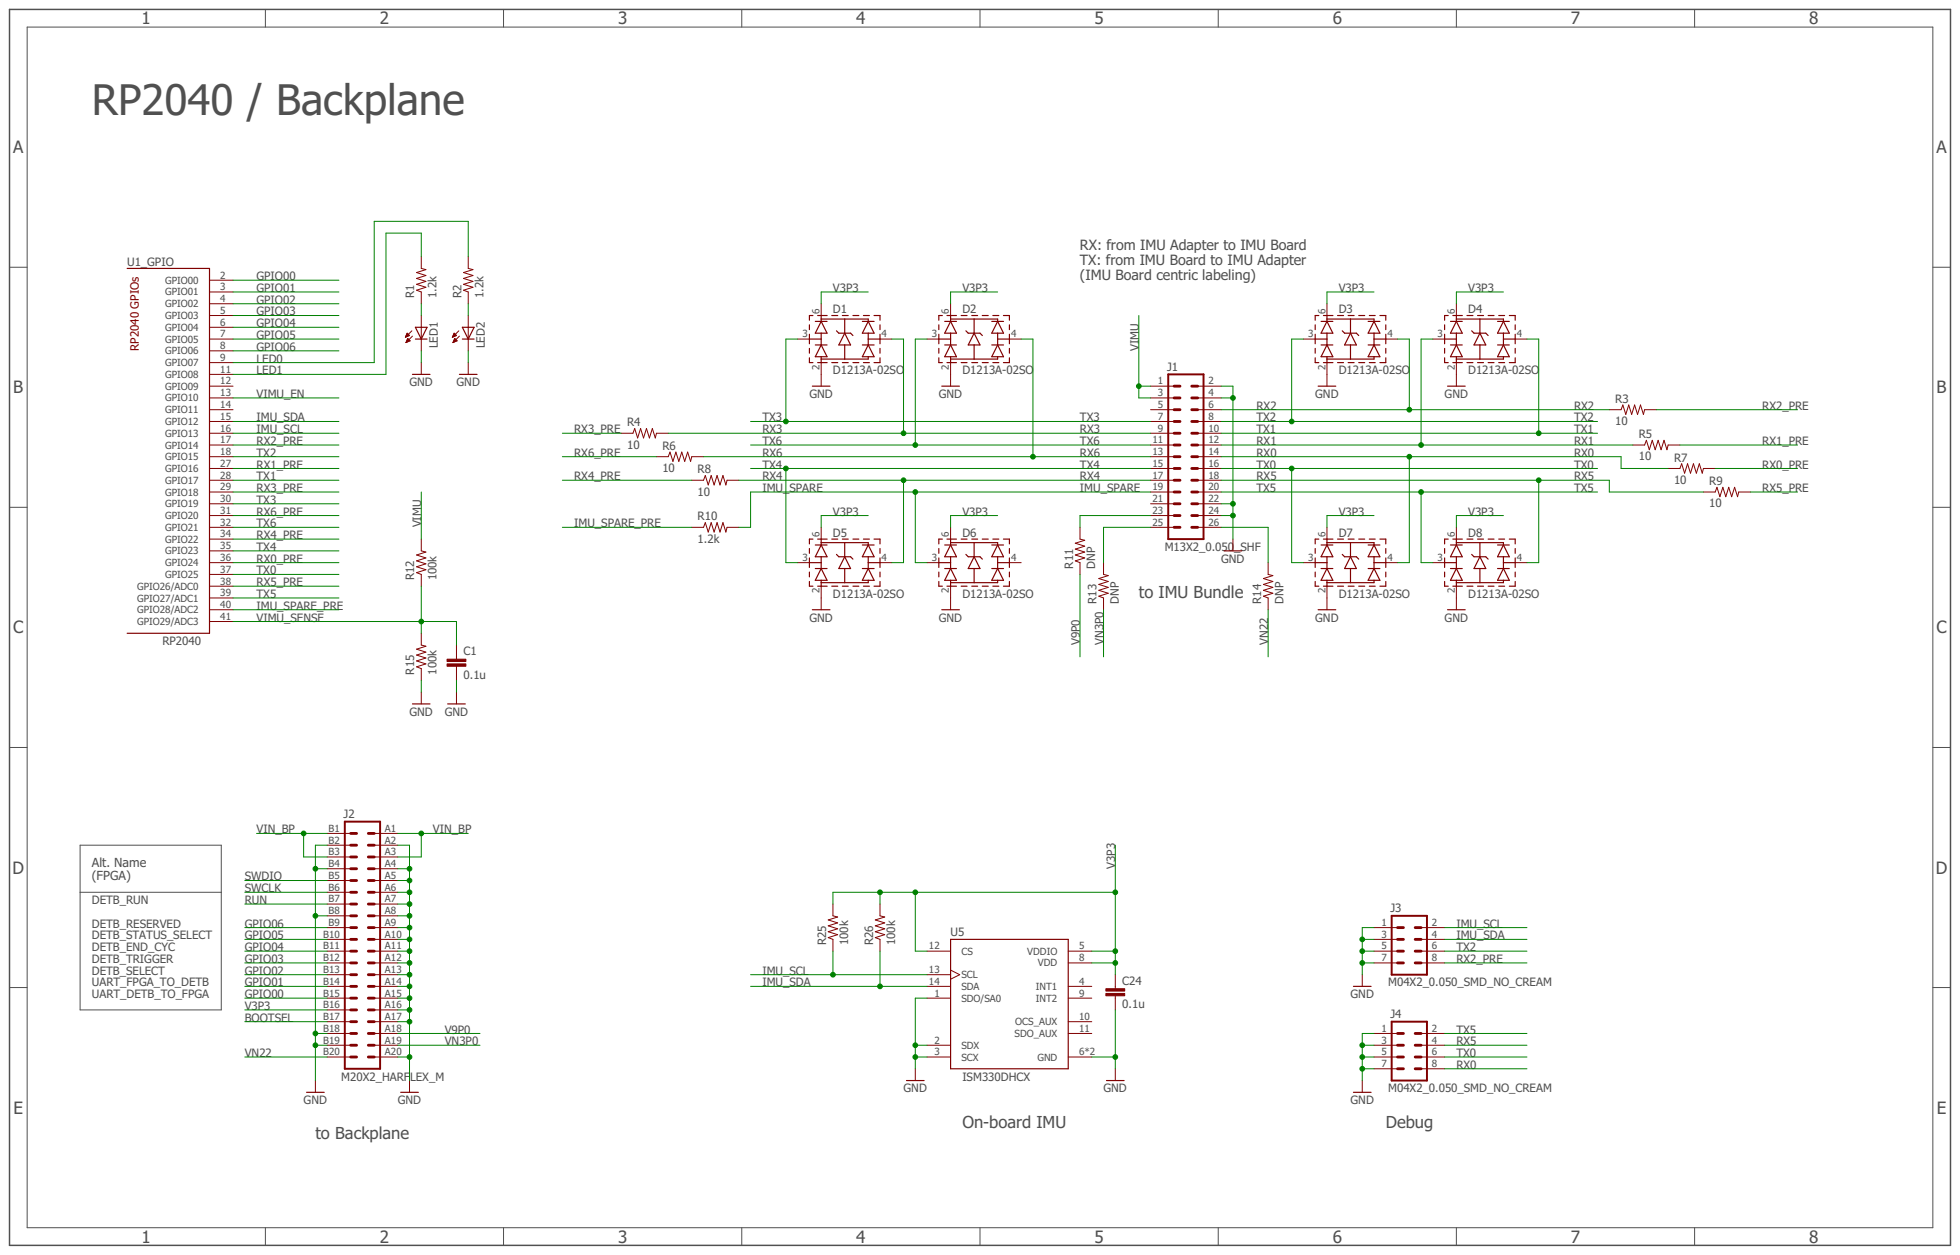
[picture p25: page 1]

RX: from IMU Adapter to IMU Board
TX: from IMU Board to IMU Adapter
(IMU Board centric labeling)

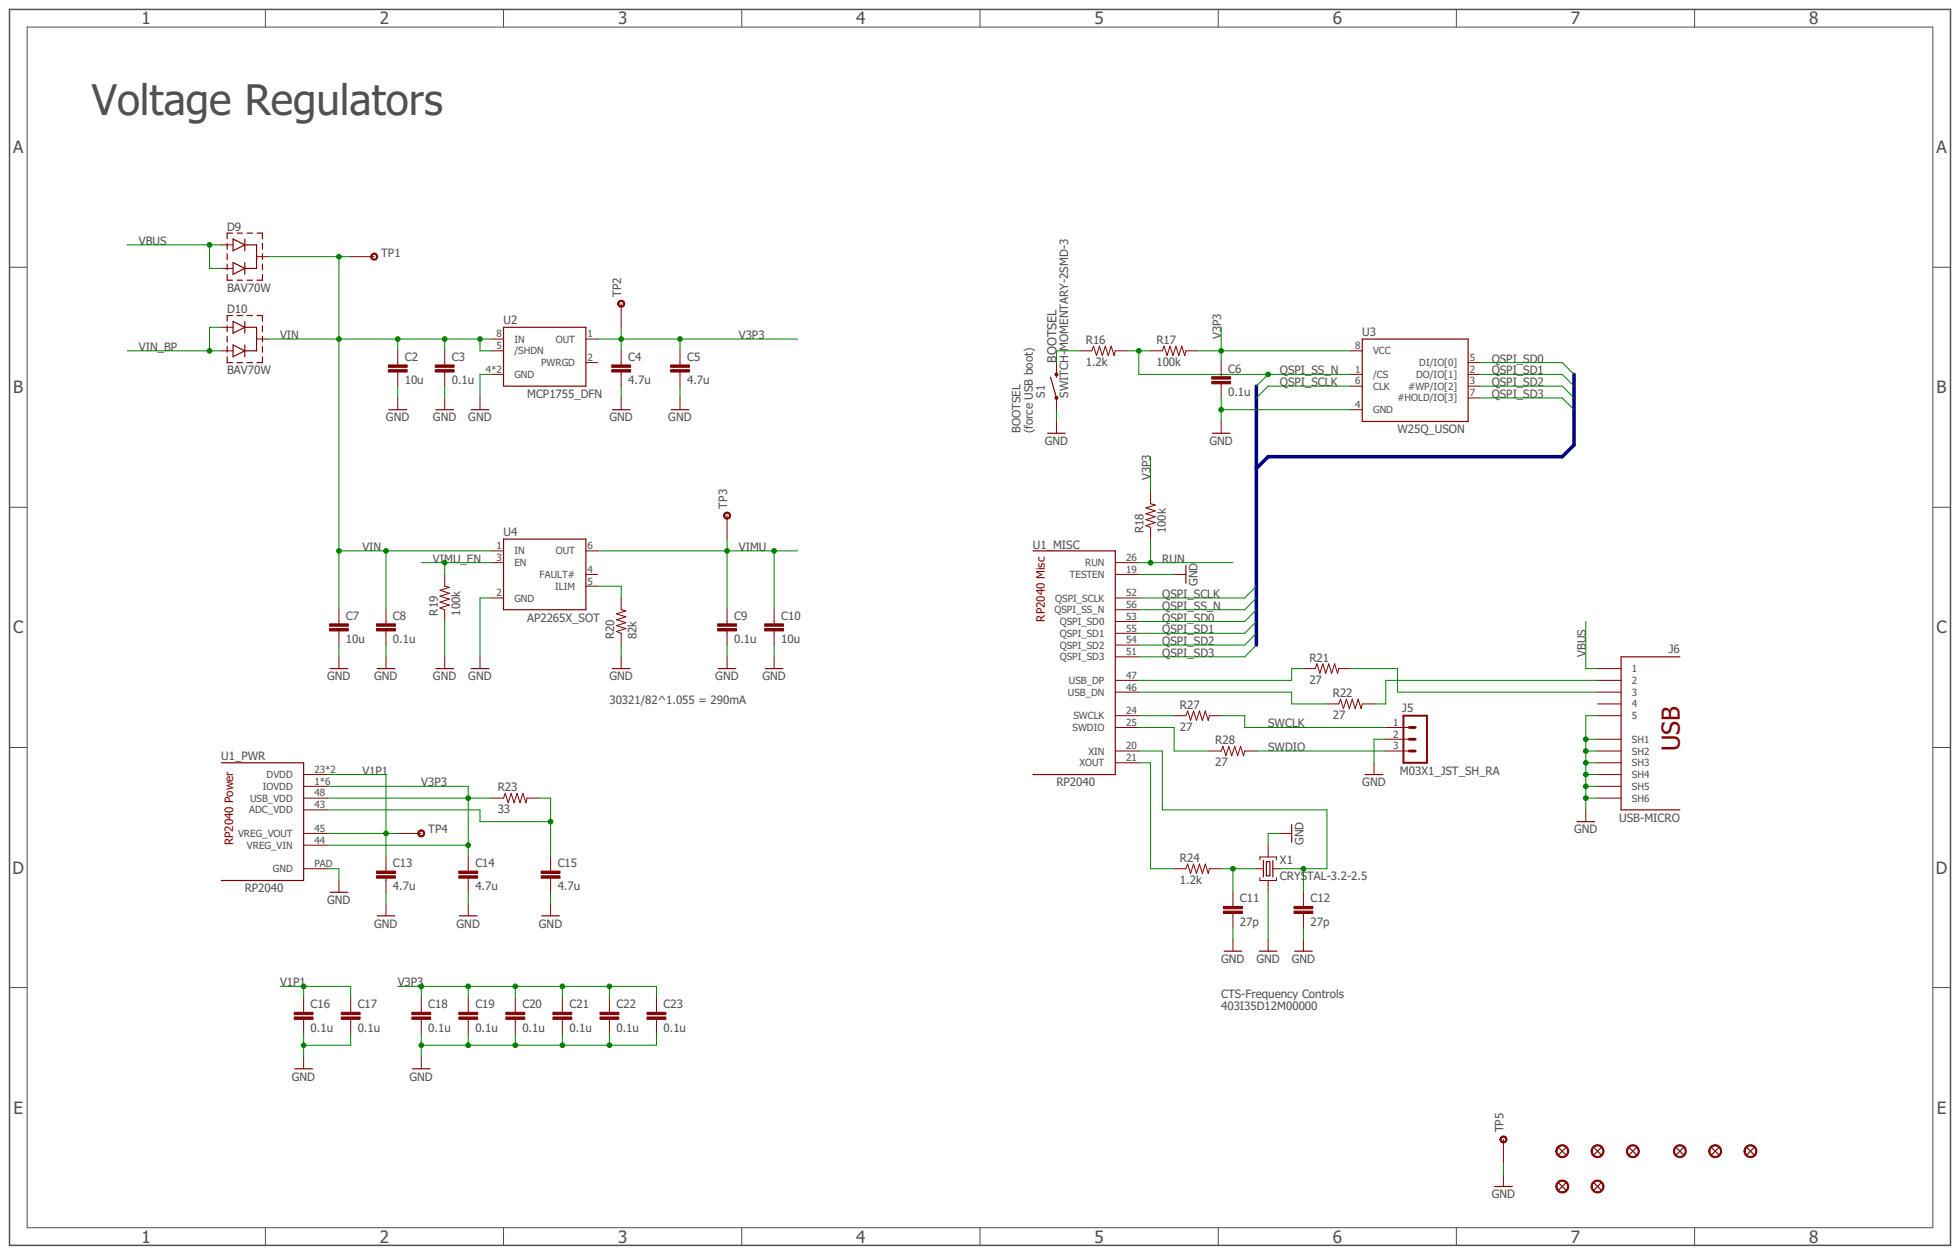
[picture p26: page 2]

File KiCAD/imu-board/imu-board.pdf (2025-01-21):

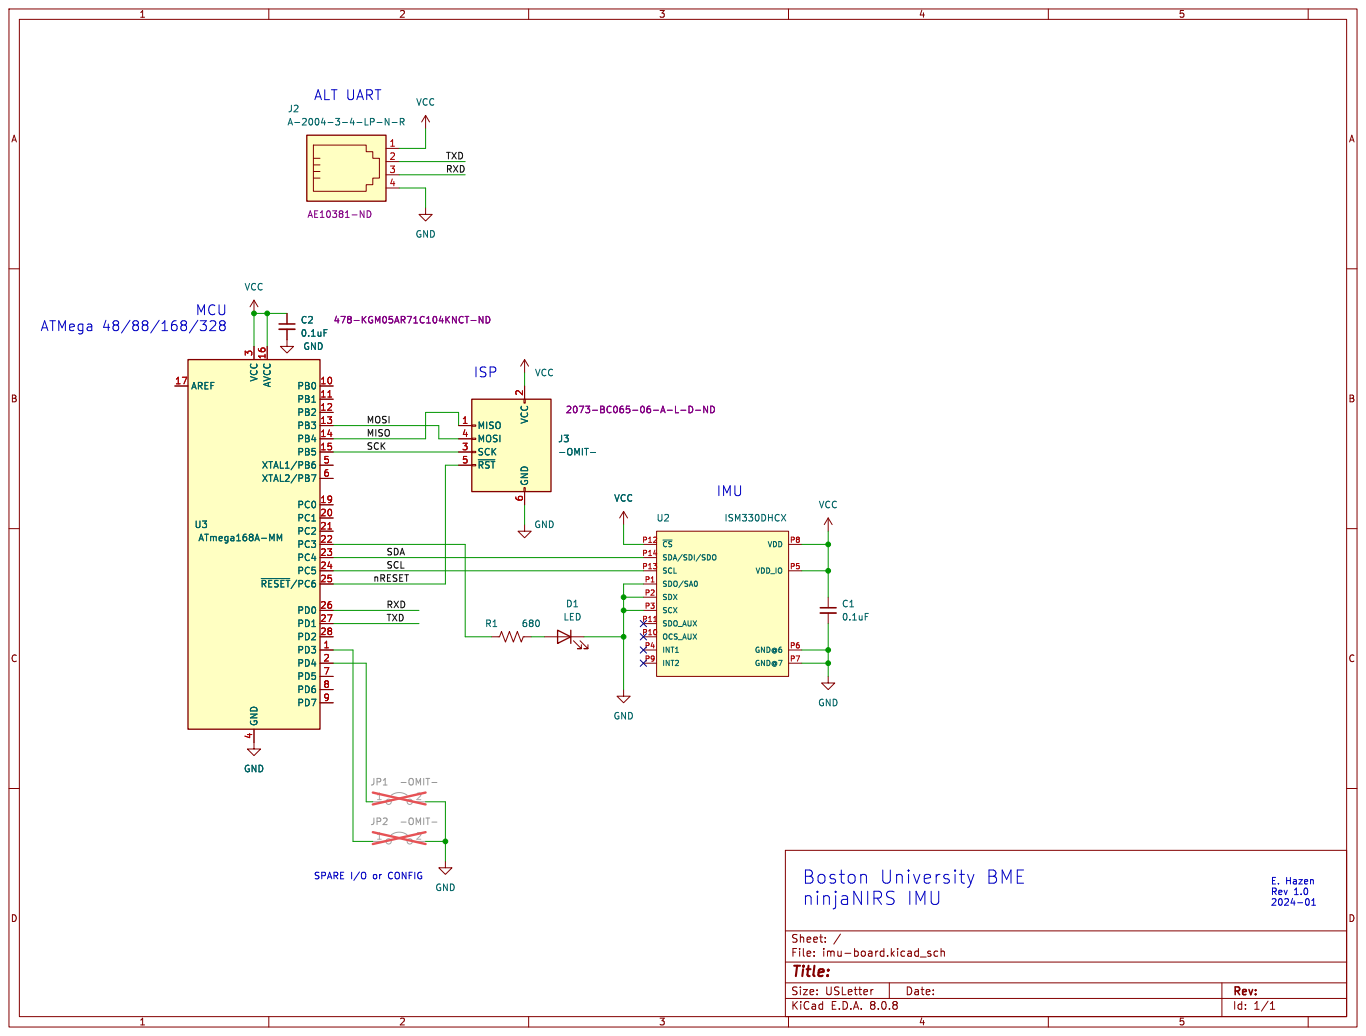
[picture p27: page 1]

2 SCK 3 MOSI 4 ~{RST} 5 GND

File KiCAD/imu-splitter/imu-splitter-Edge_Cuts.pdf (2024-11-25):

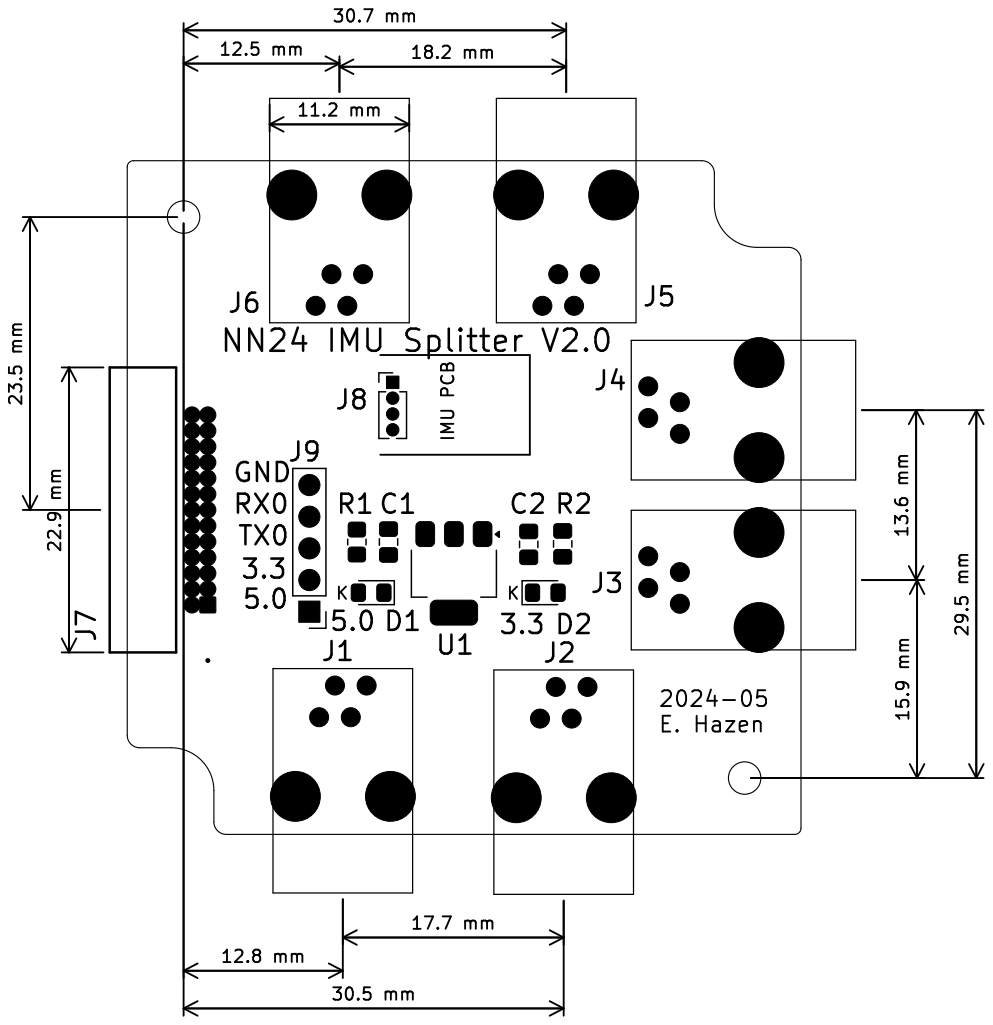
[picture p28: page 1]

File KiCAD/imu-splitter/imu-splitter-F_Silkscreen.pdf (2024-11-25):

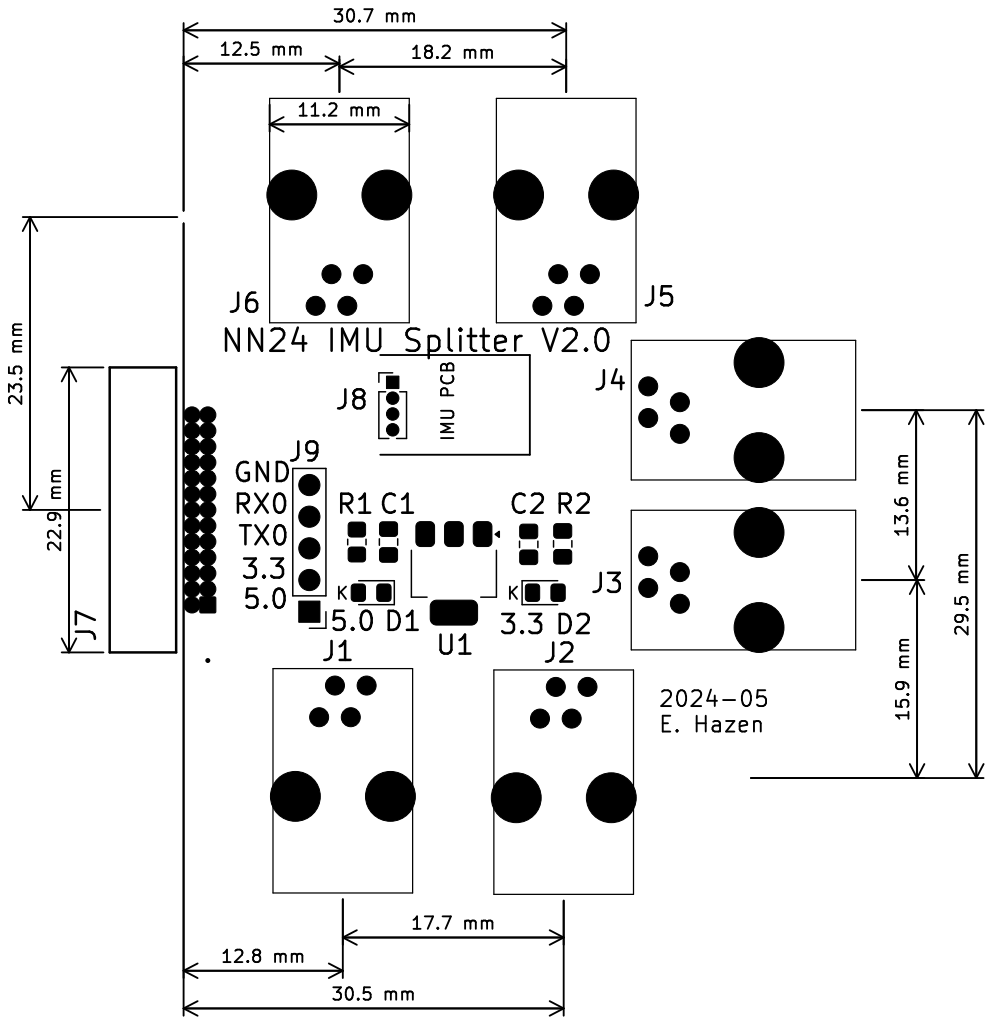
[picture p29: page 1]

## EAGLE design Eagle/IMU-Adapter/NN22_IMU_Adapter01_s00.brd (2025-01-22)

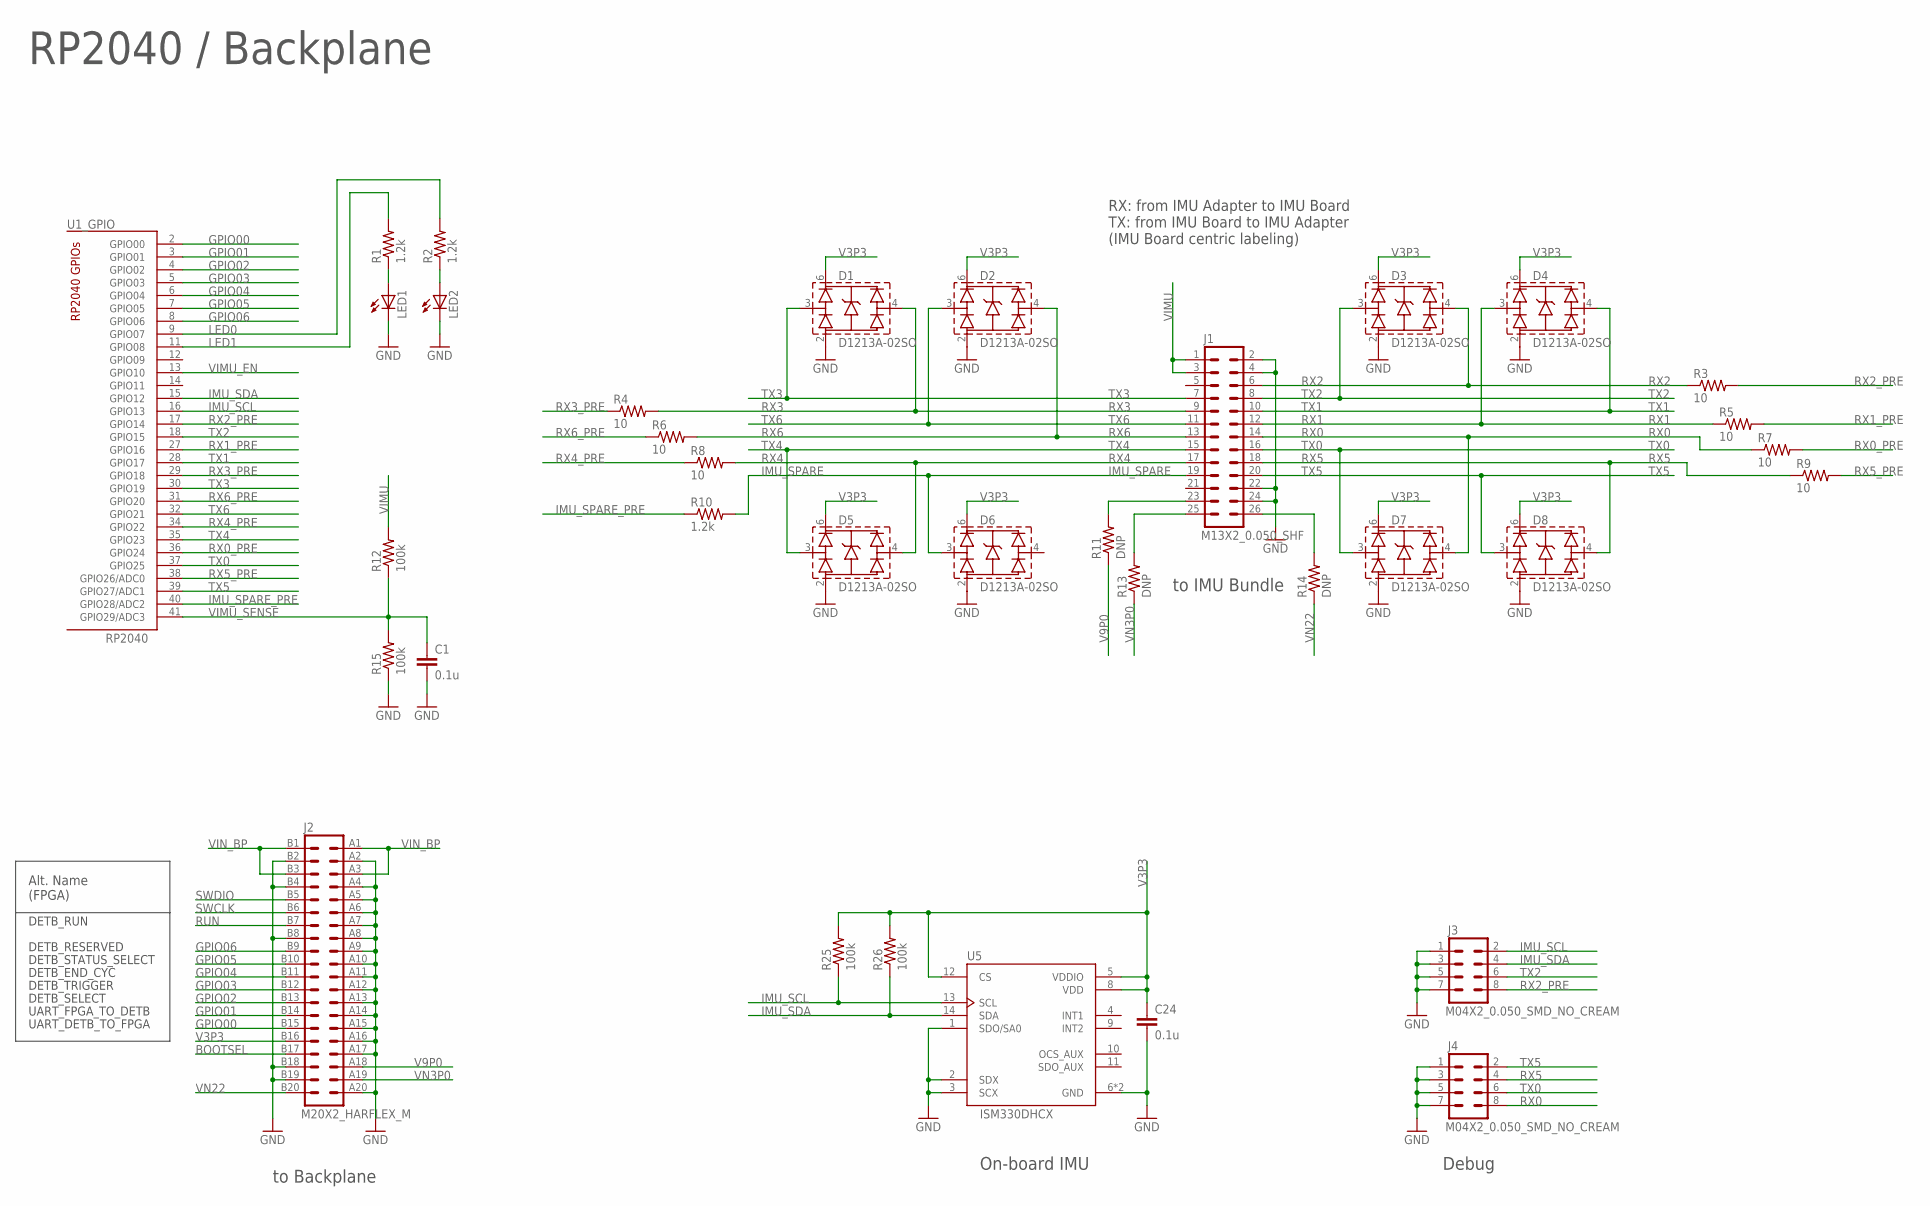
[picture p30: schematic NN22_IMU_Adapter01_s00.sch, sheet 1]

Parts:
C1, C24: 0.1u; 0402-CAP
D1, D2, D3, D4, D5, D6, D7, D8: D1213A-02SO; SOT23-6
J1: M13X2_0.050_SHF
J2: M20X2_HARFLEX_M
J3, J4: M04X2_0.050_SMD_NO_CREAM
LED1, LED2: LED0603; LED-0603
R1, R2, R10: 1.2k; 0402-RES
R3, R4, R5, R6, R7, R8, R9: 10; 0402-RES
R11, R13, R14: DNP; 0603-RES
R12, R15, R25, R26: 100k; 0402-RES
U1: RP2040; QFN-56_EP
U5: ISM330DHCX; LGA14-L

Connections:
BOOTSEL: J2.B17 (33); also elsewhere on the board
GND: C1.2, C24.2, D1.2 (VN), D2.2 (VN), D3.2 (VN), D4.2 (VN), D5.2 (VN), D6.2 (VN), D7.2 (VN), D8.2 (VN), J1.2, J1.4, J1.22, J1.24, J2.A2 (4), J2.A4 (8), J2.A5 (10), J2.A6 (12), J2.A7 (14), J2.A8 (16), J2.A9 (18), J2.A10 (20), J2.A11 (22), J2.A12 (24), J2.A13 (26), J2.A14 (28), J2.A15 (30), J2.A16 (32), J2.A17 (34), J2.A20 (40), J2.B2 (3), J2.B4 (7), J2.B8 (15), J2.B18 (35), J2.B19 (37), J3.1, J3.3, J3.5, J3.7, J4.1, J4.3, J4.5, J4.7, LED1.C, LED2.C, R15.1, U5.1 (SDO/SA0), U5.2 (SDX), U5.3 (SCX), U5.6 (GND), U5.7 (GND); also elsewhere on the board
GPIO00: J2.B15 (29), U1.2 (GPIO00)
GPIO01: J2.B14 (27), U1.3 (GPIO01)
GPIO02: J2.B13 (25), U1.4 (GPIO02)
GPIO03: J2.B12 (23), U1.5 (GPIO03)
GPIO04: J2.B11 (21), U1.6 (GPIO04)
GPIO05: J2.B10 (19), U1.7 (GPIO05)
GPIO06: J2.B9 (17), U1.8 (GPIO06)
IMU_SCL: J3.2, R25.1, U1.16 (GPIO13), U5.13 (SCL)
IMU_SDA: J3.4, R26.1, U1.15 (GPIO12), U5.14 (SDA)
IMU_SPARE: D6.3 (CH1), J1.19, R10.2
IMU_SPARE_PRE: R10.1, U1.40 (GPIO28/ADC2)
LED0: R2.2, U1.9 (GPIO07)
LED1: R1.2, U1.11 (GPIO08)
unnamed: J1.23, R11.2
unnamed: J1.25, R13.2
unnamed: J1.26, R14.2
unnamed: LED1.A, R1.1
unnamed: LED2.A, R2.1
RUN: J2.B7 (13); also elsewhere on the board
RX0: D7.4 (CH2), J1.14, J4.8, R7.1
RX0_PRE: R7.2, U1.36 (GPIO24)
RX1: D4.3 (CH1), J1.12, R5.1
RX1_PRE: R5.2, U1.27 (GPIO16)
RX2: D3.4 (CH2), J1.6, R3.1
RX2_PRE: J3.8, R3.2, U1.17 (GPIO14)
RX3: D1.4 (CH2), J1.9, R4.2
RX3_PRE: R4.1, U1.29 (GPIO18)
RX4: D5.4 (CH2), J1.17, R8.2
RX4_PRE: R8.1, U1.34 (GPIO22)
RX5: D8.4 (CH2), J1.18, J4.4, R9.1
RX5_PRE: R9.2, U1.38 (GPIO26/ADC0)
RX6: D2.4 (CH2), J1.13, R6.2
RX6_PRE: R6.1, U1.31 (GPIO20)
SWCLK: J2.B6 (11); also elsewhere on the board
SWDIO: J2.B5 (9); also elsewhere on the board
TX0: D7.3 (CH1), J1.16, J4.6, U1.37 (GPIO25)
TX1: D4.4 (CH2), J1.10, U1.28 (GPIO17)
TX2: D3.3 (CH1), J1.8, J3.6, U1.18 (GPIO15)
TX3: D1.3 (CH1), J1.7, U1.30 (GPIO19)
TX4: D5.3 (CH1), J1.15, U1.35 (GPIO23)
TX5: D8.3 (CH1), J1.20, J4.2, U1.39 (GPIO27/ADC1)
TX6: D2.3 (CH1), J1.11, U1.32 (GPIO21)
V3P3: C24.1, D1.6 (VP), D2.6 (VP), D3.6 (VP), D4.6 (VP), D5.6 (VP), D6.6 (VP), D7.6 (VP), D8.6 (VP), J2.B16 (31), R25.2, R26.2, U5.5 (VDDIO), U5.8 (VDD), U5.12 (CS); also elsewhere on the board
V9P0: J2.A18 (36), R11.1
VIMU: J1.1, J1.3, R12.2; also elsewhere on the board
VIMU_EN: U1.13 (GPIO10); also elsewhere on the board
VIMU_SENSE: C1.1, R12.1, R15.2, U1.41 (GPIO29/ADC3)
VIN_BP: J2.A1 (2), J2.A3 (6), J2.B1 (1), J2.B3 (5); also elsewhere on the board
VN3P0: J2.A19 (38), R13.1
VN22: J2.B20 (39), R14.1

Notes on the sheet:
RP2040 / Backplane
to Backplane
UART_DETB_TO_FPGA
UART_FPGA_TO_DETB
DETB_SELECT
DETB_TRIGGER
DETB_END_CYC
DETB_STATUS_SELECT
DETB_RESERVED
DETB_RUN
Alt. Name (FPGA)
to IMU Bundle
Debug
RX: from IMU Adapter to IMU Board TX: from IMU Board to IMU Adapter (IMU Board centric labeling)
On-board IMU

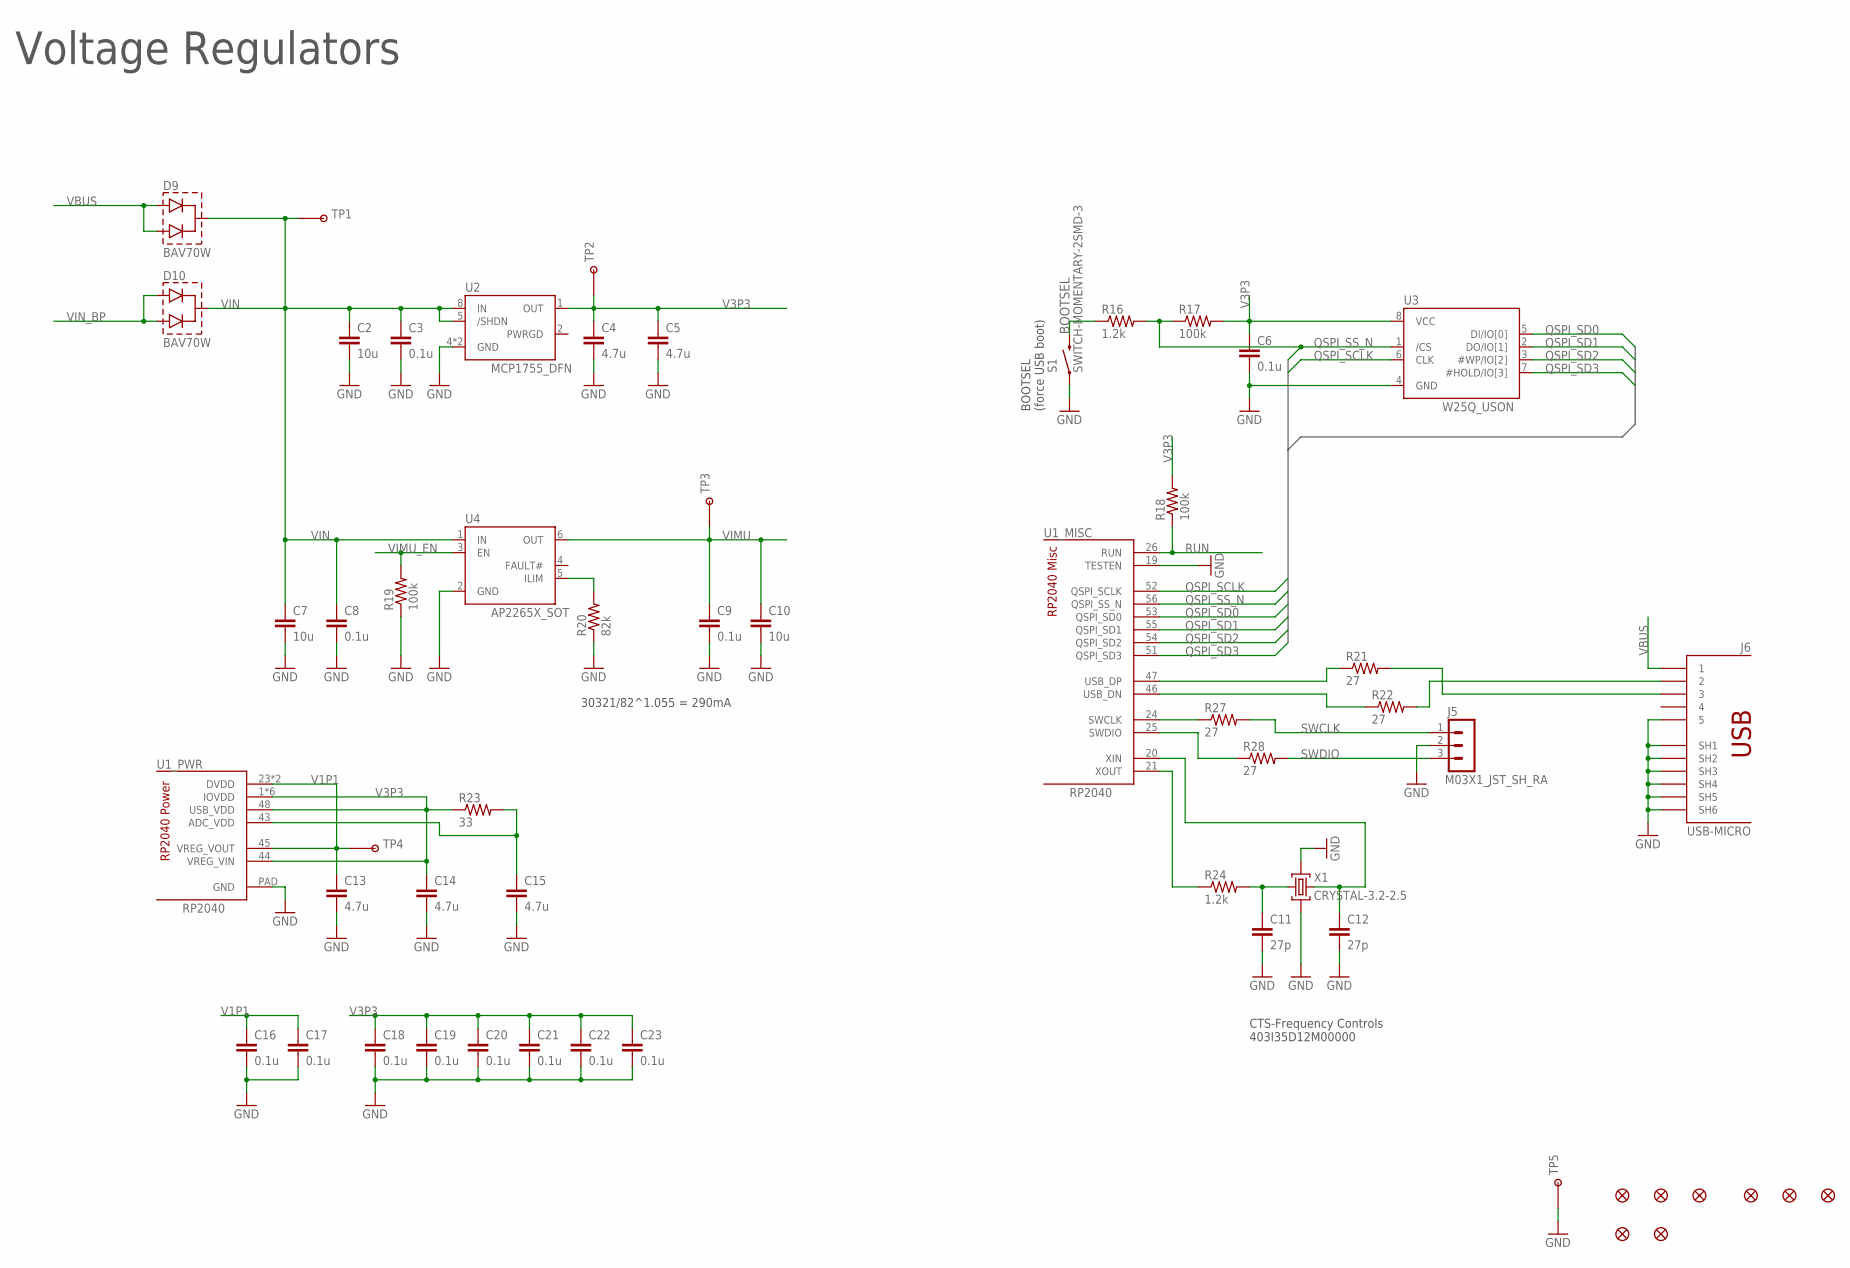
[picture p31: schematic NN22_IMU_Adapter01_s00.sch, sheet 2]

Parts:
C2, C7, C10: 10u; 0603-CAP
C3, C6, C8, C9, C16, C17, C18, C19, C20, C21, C22, C23: 0.1u; 0402-CAP
C4, C5, C13, C14, C15: 4.7u; 0402-CAP
C11, C12: 27p; 0402-CAP
D9, D10: BAV70W; SOT323
FID1, FID2, FID3, FID4, FID5, FID6, FID7, FID8: FIDUCIALUFIDUCIAL; MICRO-FIDUCIAL
J5: M03X1_JST_SH_RA; M03X1_JST_SH_SM_RA
J6: USB-MICRO
R16, R24: 1.2k; 0402-RES
R17, R18, R19: 100k; 0402-RES
R20: 82k; 0402-RES
R21, R22, R27, R28: 27; 0402-RES
R23: 33; 0402-RES
S1: SWITCH-MOMENTARY-2SMD-3; TACTILE_SWITCH_SMD-3
TP1, TP2, TP3: TESTPOINT_ROUND; TESTPAD_ROUND
TP4: TESTPOINTPADSMALL; TESTPAD_SMALL
TP5: TESTPOINT1X01; 1X01
U1: RP2040; QFN-56_EP
U2: MCP1755_DFN; DFN8_2X3MM
U3: W25Q_USON; USON8L-2X3MM
U4: AP2265X_SOT; SOT23-6
X1: CRYSTAL-3.2-2.5

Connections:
BOOTSEL: R16.1, S1.4 (2); also elsewhere on the board
GND: C2.2, C3.2, C4.2, C5.2, C6.2, C7.2, C8.2, C9.2, C10.2, C11.2, C12.2, C13.2, C14.2, C15.2, C16.2, C17.2, C18.2, C19.2, C20.2, C21.2, C22.2, C23.2, J5.2, J6.5, J6.SH1, J6.SH2, J6.SH3, J6.SH4, J6.SH5, J6.SH6, R19.1, R20.1, S1.1, TP5.1, U1.19 (TESTEN), U1.PAD (GND), U2.4 (GND), U2.P (GND), U3.4 (GND), U4.2 (GND), X1.2 (GND), X1.4 (GND); also elsewhere on the board
unnamed: R20.2, U4.5 (ILIM)
unnamed: C12.1, U1.20 (XIN), X1.3 (C2)
unnamed: C11.1, R24.2, X1.1 (C1)
unnamed: R24.1, U1.21 (XOUT)
unnamed: R21.1, U1.47 (USB_DP)
unnamed: R22.1, U1.46 (USB_DN)
unnamed: J6.2, R22.2
unnamed: J6.3, R21.2
unnamed: C15.1, R23.2, U1.43 (ADC_VDD)
QSPI_SCLK: U1.52 (QSPI_SCLK), U3.6 (CLK)
QSPI_SD0: U1.53 (QSPI_SD0), U3.5 (DI/IO[0])
QSPI_SD1: U1.55 (QSPI_SD1), U3.2 (DO/IO[1])
QSPI_SD2: U1.54 (QSPI_SD2), U3.3 (#WP/IO[2])
QSPI_SD3: U1.51 (QSPI_SD3), U3.7 (#HOLD/IO[3])
QSPI_SS_N: R16.2, R17.1, U1.56 (QSPI_SS_N), U3.1 (/CS)
RUN: R18.1, U1.26 (RUN); also elsewhere on the board
SWCLK: J5.1, R27.2; also elsewhere on the board
SWCLK_PRE: R27.1, U1.24 (SWCLK)
SWDIO: J5.3, R28.2; also elsewhere on the board
SWDIO_PRE: R28.1, U1.25 (SWDIO)
V1P1: C13.1, C16.1, C17.1, TP4.P$1, U1.23 (DVDD), U1.45 (VREG_VOUT), U1.50 (DVDD)
V3P3: C4.1, C5.1, C6.1, C14.1, C18.1, C19.1, C20.1, C21.1, C22.1, C23.1, R17.2, R18.2, R23.1, TP2.P$1, U1.1 (IOVDD), U1.10 (IOVDD), U1.22 (IOVDD), U1.33 (IOVDD), U1.42 (IOVDD), U1.44 (VREG_VIN), U1.48 (USB_VDD), U1.49 (IOVDD), U2.1 (OUT), U3.8 (VCC); also elsewhere on the board
VBUS: D9.1 (A1), D9.2 (A2), J6.1
VIMU: C9.1, C10.1, TP3.P$1, U4.6 (OUT); also elsewhere on the board
VIMU_EN: R19.2, U4.3 (EN); also elsewhere on the board
VIN: C2.1, C3.1, C7.1, C8.1, D9.3 (C), D10.3 (C), TP1.P$1, U2.5 (/SHDN), U2.8 (IN), U4.1 (IN)
VIN_BP: D10.1 (A1), D10.2 (A2); also elsewhere on the board

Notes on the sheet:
Voltage Regulators
BOOTSEL (force USB boot)
CTS-Frequency Controls 403I35D12M00000
30321/82^1.055 = 290mA

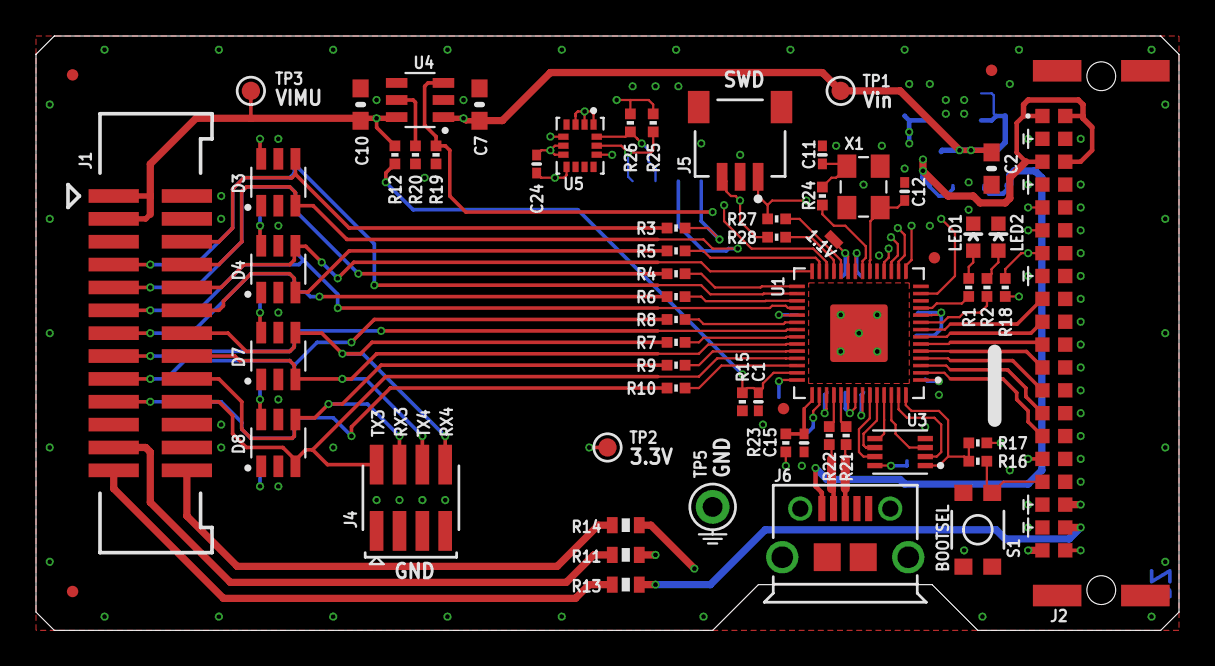
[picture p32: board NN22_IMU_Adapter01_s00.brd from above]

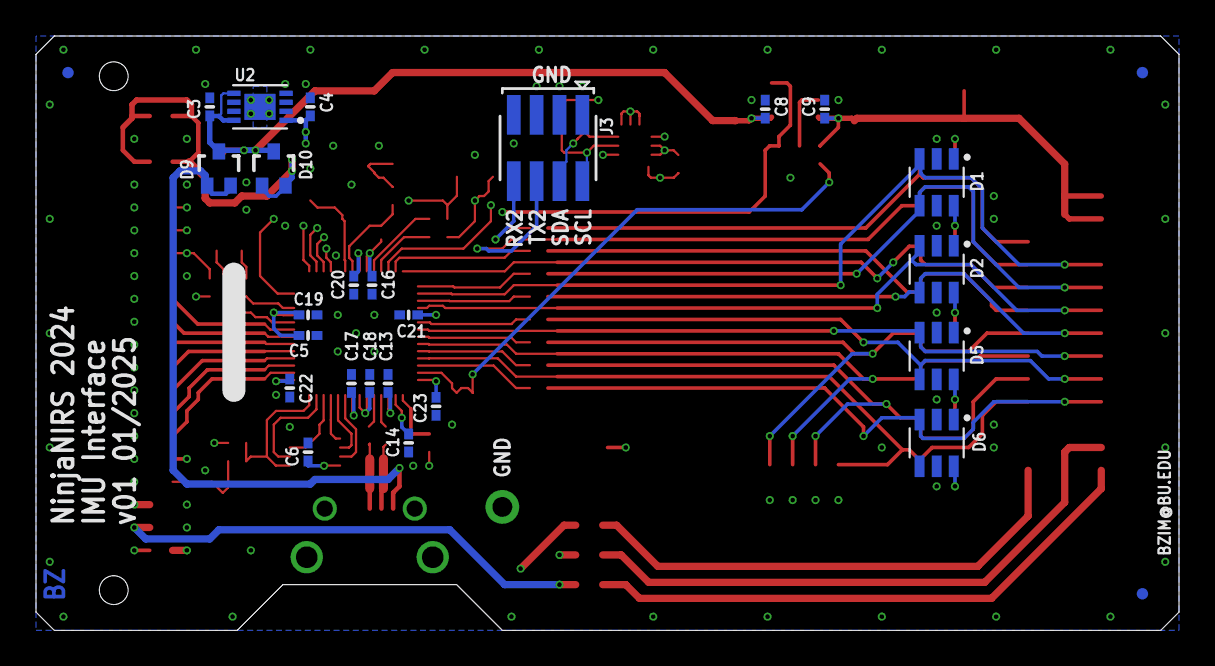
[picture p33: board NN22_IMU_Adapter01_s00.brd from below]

Board: 4 copper layers, 63.5 x 33.0 mm, 90 parts (27 on the bottom side), 72 nets.

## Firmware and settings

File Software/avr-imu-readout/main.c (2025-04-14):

/*
 * main.c - main program for AVR IMU readout (as used by NinjaNIRS)
 *
 * 
 * wait to receive any character
 * ----------------------------------------
 * Binary output:
 *   <echo> <count> <length> <checksum>
 *
 * offset 0      <echo>     = xx   echo of byte received
 * offset 1      <count>    = 14   normal data, 
 * offset 2..15  <data>     =      (7) 16-bit words of Temp, GyroX/Y/Z, Accel X/Y/Z
 * offset 16     <checksum> =      uint8_t sum of bytes at offset 1..15
 *
 * if any error occurs, <count> = 1 and the error code is somehow related
 * to the I2C error.
 *
 * ----------------------------------------
 * Text output:
 * temp,gyroX,gyroY,gyroZ,accelX,accelY,accelZ   (all signed 16-bit decimal)
 *
 * only accel can be sent by setting FIRST_VAR to 4
 */

#include <stdio.h>
#include <string.h>
#include <stdbool.h>
#include <avr/io.h>
#include <util/delay.h>
#include "uart.h"
#include "i2c.h"

#include "imu.h"
#include "imu_const.h"

// First variable to send:
//   temp = 0, gyro = 1..3, Accel = 4..6
#define FIRST_VAR 0

// send text data
// #define TEXT_DATA

// readout at fixed interval (no Rx data needed)
// #define AUTO_INTERVAL 100

// send magic number first
// #define MAGIC_NUMBER 0x5791

#ifdef MAGIC_NUMBER
const uint8_t magic_lo = MAGIC_NUMBER & 0xff;
const uint8_t magic_hi = (MAGIC_NUMBER >> 8) & 0xff;
#endif

// #define LED_BLINKS
// #define DEBUG_COMMANDS

#include "leds.h"

#ifdef AVR_TARGET
// bits for TWI interface for pull-up enable
#define TWI_PORT PORTC
#define TWI_BITS_MASK ((1 << 4) | (1 << 5))
#endif


// these work for both (jumpers on target, D3 and D4 on Arduino)
#define JUMPER_DDR DDRD
#define JUMPER_PORT PORTD
#define JUMPER_1_BIT 4
#define JUMPER_2_BIT 3

void send_data( uint8_t nb, uint8_t* d);

// dummy data for testing
static int16_t acc_test[] = { 1111, 2222, 3333, 4444, 5555, 6666, 7777 };

// buffer for text data
#ifdef TEXT_DATA
static char btext[10];
static int16_t tval;
#endif

static uint8_t loop_cnt = 0;
static int16_t acc_res[7];
static uint8_t res;
static uint8_t chr;
static bool acc_connected = false;

int main (void)
{

  USART0Init();			/* initialize USART (no interrupts) */

#ifdef AVR_TARGET
  // activate internal pull-ups on I2C pins
  TWI_PORT |= TWI_BITS_MASK;
#endif

  // activate pull-ups on jumpers
  JUMPER_PORT |= ((1 << JUMPER_1_BIT) | (1 << JUMPER_2_BIT));

  // setup I/O bits
  LED_DDR |= (1 << LED_BIT);

  i2c_init( BDIV);		/* initialize I2C */

#ifdef LED_BLINKS
  // blink the LED
  blink_led( 3, 250);		/* blink 3 times at power-up */
#endif
  
#ifdef DEBUG_COMMANDS
  // send a '*' to indicate we're alive
  USART0SendByte( '*', 0);
#endif

  while ( true) {

// --- auto interval 
#ifdef AUTO_INTERVAL
    _delay_ms( AUTO_INTERVAL);
#else

// --- respond to input data
    res = USART0ReceiveByte(0);

#ifdef DEBUG_COMMANDS
    if( res == 'T') {

#ifdef LED_BLINKS
      blink_led( 2, 100);
#endif
      // send fake data
      send_data( 14, (uint8_t *)acc_test);

    } else if( res == 'A') {

#endif

#endif      

#ifdef LED_BLINKS
      blink_led( 1, 100);
#endif

      //--- read out the IMU and send the data, either way

      // Accelerometer init
      while (!acc_connected){
	res = init_acc();
	if (res){      		/* error return */
	  send_data( 1, &res);
	  _delay_ms(250);
	  acc_connected = false;
	} else {
	  //	  chr = 'O';
	  //	  send_data( 1, &chr);
	  acc_connected = true;
	}
      }

      // simple mode, just send the data or an error packet
      res = read_acc(acc_res);
      if (res){    		/* error return */
	send_data( 1, &res);
	acc_connected = false;
      }

      // send the data
      send_data( sizeof(acc_res), (uint8_t *)acc_res);

#ifdef DEBUG_COMMANDS      

    } else {
      res = 'X';
      send_data( 1, &res);
    }      
#endif

  }

}

//
// send nb bytes of data from d to serial port
// (blocking) followed by checksum
//
void send_data( uint8_t nb, uint8_t* d) {

  // ---------- text data
#ifdef TEXT_DATA
  if( nb == sizeof(acc_res)) {	/* normal 7-word data */
    for( int i=2*FIRST_VAR; i<sizeof(acc_res); i += 2) {
      tval = d[i] | (d[i+1] << 8);
      snprintf( btext, sizeof(btext), "%d", tval);
      USART0SendString( btext, 0);
      if( i == sizeof(acc_res)-2) {
	USART0SendByte( '\r', 0);
	USART0SendByte( '\n', 0);
      } else {
	USART0SendByte( ',', 0);
      }	
    }
  }
#else

  // ---------- binary data
#ifdef MAGIC_NUMBER
  USART0SendByte( magic_lo, 0);
  USART0SendByte( magic_hi, 0);
#endif  

  uint8_t sum = nb;
  USART0SendByte( nb, 0);
  for( uint8_t i=2*FIRST_VAR; i<nb; i++) {
    USART0SendByte( d[i], 0);
    sum += d[i];
  }
  USART0SendByte( sum, 0);
#endif
}

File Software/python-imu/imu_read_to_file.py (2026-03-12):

#!/usr/bin/python3
#
# imu_read_to_file.py
#
# read and plot gyro and acceleration data from IMU
# expects IMU firmware which is triggered by a recieved byte
# and sends 6 comma-separated integers per trigger
#
# write specified number of samples to file
#
# usage: imu_read_to_file.py <samples> <interval_ms> <file_name>
#     <samples> is number of samples
#     <interval_ms> is interval between samples in ms
#     <file_name> is (text) file to record data in
#
# current date/time is included at start of each record
#


import serial
import sys
import time
import datetime

# connect to device.  For windows use e.g. COM3 for device
ser = serial.Serial('/dev/ttyUSB0', 9600)
# ser = serial.Serial('COM3', 9600)

# trigger byte to send to IMU
trig = b'\xff';

# parse arguments
if(len(sys.argv) > 3):
    samples = int(sys.argv[1])
    samp_interval = int(sys.argv[2])
    fname = sys.argv[3]
else:
    print("Usage: ", sys.argv[0], " <samples> <interval_ms> <file_name>")
    sys.exit()

# get starting time in ms
start_ms = round(time.time()*1000)
ns = 0

try:
    f = open(fname, "w", encoding="utf-8")
except Exception as e:
    print("Error opening file")
    sys.exit()

# loop over specified number of samples
for i in range(samples):
    now = datetime.datetime.now()
    time_now = round(time.time()*1000)-start_ms # get the time
    ser.write(trig)
    bdata = ser.readline()                      # read data from IMU
    tdata = bdata.decode('utf-8')               # convert to text
    # write date/time stamp in quotes
    f.write( "\"")
    f.write( str(now))
    f.write( "\",")
    # write the IMU data
    f.write( tdata)
    print(ns,"/",samples,end="\r")               # print sample# for progress
    ns = ns + 1
    # delay until interval has elapsed
    while True:
        our_time = round(time.time()*1000)-start_ms
        if our_time - time_now > samp_interval:
            break;

f.close()

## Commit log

2024-01-10 First placement with ATTiny10
    [ATTINY10-MAHR.step, ISM330DHCX.step, imu-board.kicad_pcb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]
2024-01-11 fiddling with placement in develop
    [imu-board.kicad_pcb, imu-board.kicad_sch]
2024-01-11 test 12x8 mm placement
    [imu-board.kicad_pcb, imu-board.kicad_sch]
2024-01-11 candidate layout without RJ connector included
    [imu-board.kicad_pcb, imu-board.kicad_sch]
2024-01-11 add splitter
    [1551R.dxf, 1551T.dxf, A-2004-3-4-Group.step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]
2024-01-11 tentative placement of splitter
    [1551R.dxf, SHF-113-01-L-D-RA.step, SHF-113-01-L-D-RA.stp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]
2024-01-16 close to final IMU layout
    [imu-board-B_Cu.gbr, imu-board-B_Mask.gbr, imu-board-B_Silkscreen.gbr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]
2024-01-17 IMU and adapter ready to go?
    [imu-adapter-B_Cu.gbr, imu-adapter-B_Mask.gbr, imu-adapter-B_Silkscreen.gbr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]
2024-01-17 again fix POS file
    [imu-board-all-pos.csv]
2024-01-18 add RJ adapter
    [imu-rj-adapter.kicad_pcb, imu-rj-adapter.kicad_sch]
2024-01-24 updates before v1 fab
    [c-5787082-2-a-3d.stp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]
2024-01-24 fix silkscreen and move IMU PCB a bit
    [imu-splitter-B_Cu.gbr, imu-splitter-B_Mask.gbr, imu-splitter-B_Silkscreen.gbr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]
2024-02-14 Update KiCAD, start software
    [imu-adapter.kicad_sch, imu-rj-adapter.kicad_sch, imu-splitter-digikey.csv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]
2024-03-03 redo makefile
    [BC065-06-A-L-D.STEP, LGA-14L_STM.step, imu-board.kicad_pcb]
2024-03-07 KiCAD 8: Update schem P/N on 26 pin header to RA
    [imu-splitter.kicad_sch]
2024-03-14 Add Arduino test code
2024-03-19 Update schematic for correct U1 part number
    [imu-splitter.kicad_sch]
2024-05-06 Update splitter to V2.0
    [imu-splitter.kicad_pcb, imu-splitter.kicad_sch]
2024-05-08 working on 3D of box
    [1551TGY.stp, 1551T_Box.step, 1551T_Lid.step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]
2024-05-08 Candidate V2 layout
    [1551T_Lid_transparent.FCStd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]
2024-05-08 As built V2.0
    [imu-splitter-BOM.csv, imu-splitter-DigiKey5.csv, imu-splitter.kicad_sch]
2024-11-26 imu-test for SCOS BP demo
    [sample_imu_data.csv, sample_imu_data_1.ods]
2024-12-04 tweak for BP IMU test
2024-12-04 add IMU demo python
2025-01-21 V2 IMU pcb candidate
    [BOM.csv, BOM_for_PCBway.xlsx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]
2025-01-21 Update to Rev 2 IMU board, README
2025-01-21 IMU board V2 release candidate
    [BOM_for_PCBway.xlsx, imu-board.kicad_sch]
2025-01-21 working on even smaller version
    [imu-board.kicad_pcb]
2025-01-21 another small layout, unrouted
    [imu-board.kicad_pcb]
2025-01-22 Added adapter board.
    [NN22_IMU_Adapter01_s00.brd, NN22_IMU_Adapter01_s00.sch, NN22_IMU_Adapter01_s00_BOM.xls]
2025-01-22 Small change in adapter copper pour.
    [NN22_IMU_Adapter01_s00.brd]
2025-01-23 revised V2 draft layout for review
    [imu-board.kicad_pcb, imu-board.kicad_sch]
2025-01-23 cosmetic tweaks to V2.0
    [imu-board.kicad_pcb, imu-board.kicad_sch]
2025-02-11 New triggered readout for Roblyer blood pressure test
    [BOM_splitter_PCBway.xlsx, NN22_IMU_Adapter01_s00.XYRS.csv, NN22_IMU_Adapter01_s00_BOM.xls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]
2025-02-26 correct gerbers now V2.1
    [imu-board-B_Cu.gbr, imu-board-B_Mask.gbr, imu-board-B_Silkscreen.gbr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]
2025-02-26 modify avr-imu-gpio-test for 10x prescale for BP project
2025-04-07 as built IMU V2.1
    [imu-board-B_Cu.gbr, imu-board-B_Mask.gbr, imu-board-B_Silkscreen.gbr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]
2025-05-13 consolidate files for re-order
    [NN22_IMU_Adapter01_s00.XYRS.csv, NN22_IMU_Adapter01_s00_BOM.xls, imu-board-v2.1-BOM.xlsx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]
2025-10-21 new firmware, IMU box
    [imu-box.stl, scope_10.csv, scope_11.csv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]
2025-10-21 update the IMU boxes
    [imu-board.step, imu-board.stl, imu-box-small-25mm.stl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]
2026-03-12 fix plot demo, add file demo
    [imu_demo.py, imu_read_to_file.py, main.c]

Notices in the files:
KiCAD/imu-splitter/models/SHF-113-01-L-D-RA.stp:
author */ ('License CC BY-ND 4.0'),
